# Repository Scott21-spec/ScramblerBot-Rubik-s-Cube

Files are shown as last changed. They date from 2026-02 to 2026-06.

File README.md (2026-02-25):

# ScramblerBot-Rubik's-Cube-For WCA Competitions
Robot capaz de resolver o desarmar cualquier cubo de rubik 3x3 con el uso servomotores, cámara e inteligencia artificial para la detección de colores, figuras o números.

Es la mejor opción para su uso en las competencias internacionales y nacionales de cubo de rubik (WCA), debido a que sólo se coloca el cubo dentro del robot sin necesidad de modificar el cubo o utilizar un cubo especial para su reconocimiento del estado actual.

Modos de uso:
  - Modo de Desordenamiento (Scrambler mode): 
En este modo, el sistema actúa como un actuador esclavo para competencias oficiales. Recibe de forma remota una secuencia de desordenamiento (algoritmo de scramble) validada por la WCA. Tras la ejecución mecánica automatizada de los movimientos, el servidor web local genera un reporte digital en formato PDF. Este documento incluye el registro exacto de la secuencia aplicada, el algoritmo de resolución correspondiente y representaciones gráficas del estado final del cubo (planos 2D y renderizado 3D). Por normativas de seguridad y confidencialidad competitiva, el acceso a este reporte es de carácter restringido, alojándose únicamente en el entorno del servidor para la validación exclusiva de los jueces o administradores del torneo.

  - Modo de Autogeneración y Entrenamiento (Auto-Scramble & Practice Mode):
Concebida como una herramienta de entrenamiento para competidores (speedcubers), esta modalidad permite al microcontrolador generar de manera autónoma una secuencia aleatoria de desordenamiento que cumple estrictamente con los estándares y métricas de la WCA. Una vez que el robot aplica mecánicamente la secuencia generada, el sistema emite un reporte digital homólogo al de la Modalidad 1. A diferencia del modo oficial, este documento es de acceso público y descargable a través de la interfaz web, permitiendo al usuario analizar el estado del cubo, la secuencia aplicada y la solución teórica propuesta para fines de estudio y práctica.

  - Resolución Optimizada (Solve Mode):
Orientada al análisis algorítmico, esta función permite evaluar el estado físico actual de un cubo ingresado por el usuario utilizando el sistema de visión artificial integrado. A partir del mapeo de las caras, el procesador calcula la ruta de resolución más corta (optimizando la cantidad de movimientos requeridos) y procede a su ejecución mecánica. Finalmente, el sistema documenta el proceso generando un reporte descargable que detalla el estado inicial detectado, la cinemática de los movimientos aplicados y la solución óptima ejecutada.

Proyecto de la materia 'Proyecto 3' del 8vo semestre de la carrera Mecatrónica - Facultad de Ingeniería - Universidad Nacional de Asunción - San Lorenzo - Paraguay.

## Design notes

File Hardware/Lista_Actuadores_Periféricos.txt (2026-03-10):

- Servomotores MG996R: (2)
  + Voltaje de operación: 6V
  + Corriente: 500mA - 900mA
  + Corriente maxima: 2.5A
  + Pines: 6V - PWM - GND

- Pantalla LCD 20x4: (1)
  + Voltaje de operación: 5V
  + Corriente: 60mA
  + Pines: 
    *VSS: GND 
    *VDD: 5V
    *Vo: potenciometro (5V y GND en los extremos)
    *RS: PCF8574
    *RW: PCF8574
    *E: PCF8574
    *D4 - D7: PCF8574
    *A: resistencia 220ohm y 5V 
    *K: colector del transistor S8050 (base a PCF8574 con resistencia 4,7kohm a 5V, y emisor a GND)

- Modulo Arducam OV2640: (1)
  + Voltaje de operación: 3.3V
  + Corriente: 200mA
  + Pines: SCK, MOSI, MISO, CS, VCC, GND, SDA, SCL

- MCU ESP32-S3-WROOM-1-N8R8: (1)
  + Clock: 40MHz
  + Voltaje: 3.3V
  + Corriente: 500mA
  + Flash: 8MB Quad SPI
  + SPRAM: 8MB Octal SPI
  + Pines:
    * EN: High -> ON (resistencia de 10k conectado a 3.3V, pulsador conectado a tierra, capacitor 0.1uF a tierra)
    * IO35, I036, IO37: NO USAR (destinado para el PSRAM)
    * IO46, IO47: NO USAR 
    * IO0: conectar a un pulsador a GND

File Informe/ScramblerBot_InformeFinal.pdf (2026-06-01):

SCRAMBLER BOT: ROBOT PARA
LA RESOLUCIÓN DEL CUBO RUBIK

Proyecto MCT
2026

### 1. Resumen del proyecto

El proyecto consiste en el diseño y desarrollo de una placa electrónica para un robot capaz inspeccionar y operar un Cubo de Rubik 3x3 de manera automatizada. El sistema utiliza una cámara para capturar el estado del cubo y un microcontrolador ESP32-S3-WROOM-1 para procesar la información y controlar servomotores encargados de realizar los movimientos necesarios. Además, se incorpora una pantalla LCD manejada por expansores I2C para la visualización del estado del sistema con el tiempo aproximado de demora, y conectividad WiFi para la comunicación con una computadora externa.

### 2. Abstract

The project consists of designing and developing an electronic board for a robot capable of automatically inspecting, and operating a 3x3 Rubik’s Cube. The system uses a camera to capture cube’s state and an ESP32-S3-WROOM-1 microcontroller to process the information and control servomotors responsible for performing the required movements. Additionally, an LCD screen controlled by I2C expanders is included to display system’s status with an approximate delay time, and WiFi connectivity is provided for communication with an external computer.

### 3. Estado del arte

Diversos trabajos han abordado la resolución automática del cubo Rubik mediante la integración de visión artificial, algoritmos de resolución y sistemas robóticos.

[1] David Gilday (ingeniero de ARM Holdings) es el creador de MindCub3r que es un robot de dos actuadores ("brazo/jaula ²

"plataforma giratoria") utilizando LEGOs para demostrar la eficiencia de los procesadores embebidos ARM en ferias tecnológicas internacionales, y en este blog demuestra como logró manipular cubos complejos sin usar decenas de motores.

D. Gilday, "How I Created the ARM Powered Android LEGO Cube Solving Robot,"ARM Developer Community Blogs, Sep. 11, 2013. [Online] Disponible en:

https://developer.arm.com/community/arm-community-blogs/b/internet-of-things-blog/posts/how-i-created-the-arm-powered-android-lego-7x7x7-cube-solving-robot. (https://developer.arm.com/community/arm-community-blogs/b/internet-of-things-blog/posts/how-i-created-the-arm-powered-android-lego-7x7x7-cube-solving-robot)

[2] Uno de los algoritmos más utilizados para la resolución del cubo Rubik es el método
de dos fases desarrollado por Herbert Kociemba. Este algoritmo permite obtener soluciones eficientes en un número reducido de movimientos (aproximadamente 20 movimientos), siendo ampliamente utilizado en aplicaciones robóticas debido a su rapidez y confiabilidad.
H. Kociemba, “Two-Phase Algorithm for Solving Rubik’s Cube,” 2010. [Online] Disponible en:

https://kociemba.org/cube.htm

Camila Cáceres Kowalewski, 0982112185, camila.caceres@fiuna.edu.py Esteban Orlando Ruiz Martinez, 0983518648, eruiz@fiuna.edu.py

[3] En el ámbito de la robótica, existen implementaciones que combinan visión artificial y control de actuadores. Por ejemplo, en el trabajo presentado por Owolabi et al., se desarrolla un robot capaz de resolver el cubo Rubik utilizando procesamiento de imágenes para identificar colores y motores para ejecutar los movimientos.
O. Owolabi, A. O. Adewumi, and O. O. Oladipo, “Development of a Rubik’s Cube Solving Robot,” International Journal of Engineering Research & Technology (IJERT), vol. 8, no. 11, 2019.
[4] Asimismo, en proyectos académicos se ha explorado el uso de plataformas embebidas como Raspberry Pi para integrar la captura de imágenes, el procesamiento y el control de actuadores en un solo sistema, destacando la viabilidad de soluciones compactas y de bajo costo.
S. Tharayil and A. K. S, “Design and Implementation of Rubik’s Cube Solving Robot using Raspberry Pi,” International Journal of Advanced Research in Electrical, Electronics and Instrumentation Engineering, vol. 6, no. 6, 2017.

Estos trabajos demuestran que la resolución automática del cubo Rubik es un problema ampliamente estudiado, donde la combinación de algoritmos eficientes, visión artificial, control de actuadores y una buena elección de la mecánica permite desarrollar sistemas funcionales y de bajo costo. El presente proyecto se basa en estos enfoques, incorporando el diseño de una PCB dedicada para integrar todos los módulos en un sistema compacto.

### 4. Descripción

El proyecto "Scrambler Bot" propone el desarrollo de un prototipo comercial mecatrónico orientado a resolver los cuellos de botella logísticos y los errores humanos (mis-scrambles) presentes en el desordenado manual de los Cubos de Rubik durante competiciones oficiales de la WCA (World Cube Association) y en las sesiones de enseñanza en academias de speedcubing. A diferencia de las costosas alternativas industriales de múltiples motores, este sistema implementa una arquitectura cinemática optimizada de una base giratoria y un brazo manipulador controlada por servomotores de alto torque. Esta solución eficiente se gestiona a través de una placa de circuito impreso (PCB) de diseño propio gobernada por un microcontrolador ESP32-S3, el cual no solo ejecuta las rutinas mecánicas con precisión, sino que integra un módulo de cámara (OV2640) para validar ópticamente el estado del cubo mediante algoritmos de visión artificial, garantizando que el desorden final coincida matemáticamente con el estándar oficial exigido.

La motivación principal detrás de esta iniciativa radica en el gran desafío multidisciplinario que representa, exigiendo la integración armónica de diseño electrónico, programación de sistemas embebidos y diseño. De esta forma, el proyecto busca transformar un problema logístico documentado dentro de la comunidad de speedcubers en un producto de hardware funcional, elegante y asequible, demostrando cómo una ingeniería eficiente puede generar soluciones con un claro potencial de escalabilidad comercial.

### 5. Objetivos

a. General

Diseñar la placa de circuito impreso para el control de un sistema automatizado de resolución del Cubo de Rubik.

b. Específicos
1. Evaluar las alternativas mecánicas para la manipulación del cubo.
2. Diseñar la arquitectura electrónica general del sistema para la alternativa elegida.
3. Seleccionar los componentes adecuados para la implementación de la placa PCB.
4. Realizar el diagrama de bloques del sistema con sus protocolos de comunicación y alimentación correspondientes.
5. Elaborar el esquemático y conexiones de los componentes electrónicos de la placa.
6. Diseñar la PCB integrando el microcontrolador, la cámara, la pantalla LCD, la alimentación y las salidas para actuadores.
7. Implementar las rutinas de software para el control PWM de los actuadores y el procesamiento de la interfaz de visión, validando la comunicación inalámbrica mediante WiFi entre el sistema electrónico y una computadora externa.

### 6. Esquema general del proyecto

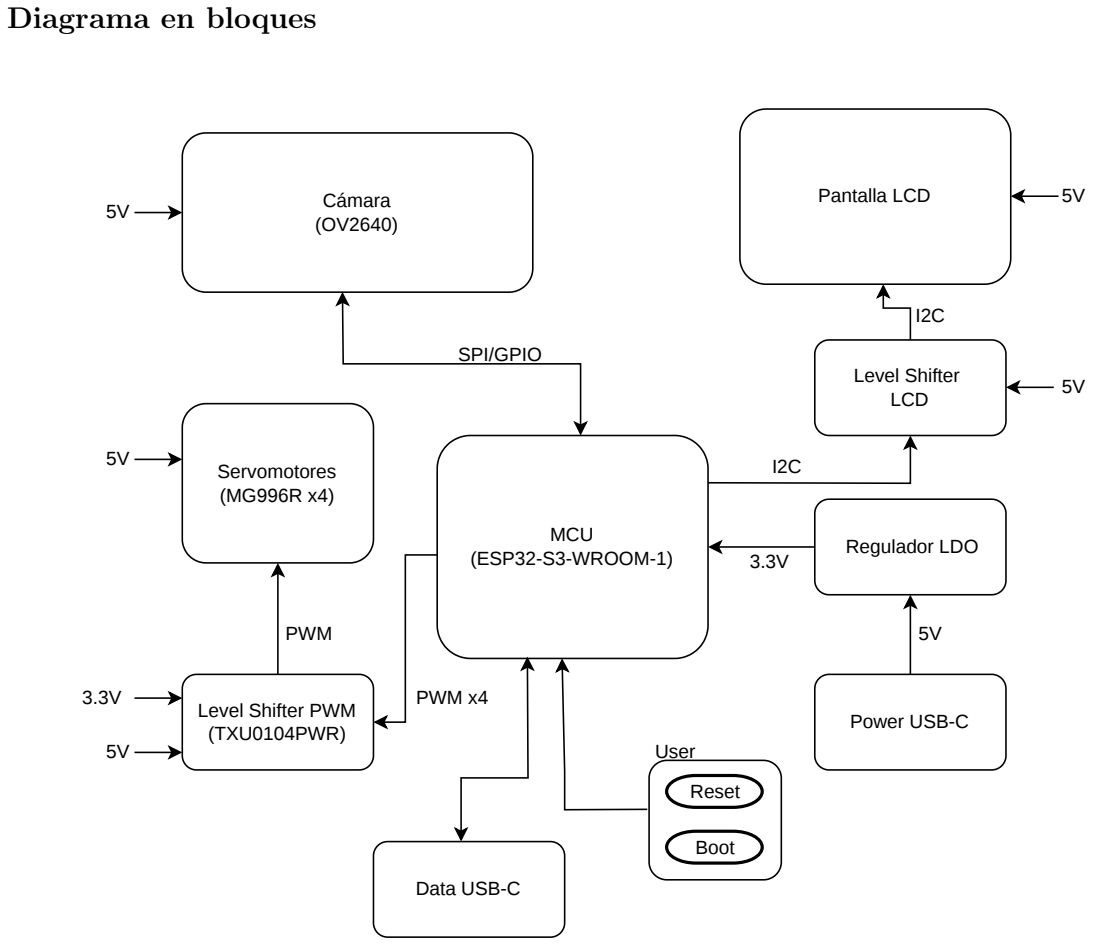
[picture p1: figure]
Diagrama en bloques; MCU (ESP32-S3-WROOM-1); Cámara (OV2640); Level Shifter LCD; Power USB-C; Pantalla LCD; Level Shifter PWM (TXU0104PWR); Servomotores (MG996R x4); Reset; Boot; User; SPI/GPIO; PWM x4; PWM; Regulador LDO; Data USB-C

Descripción de las partes

1. Microcontrolador: ESP32-S3-WROOM-1-N8R8

Encargado de coordinar el funcionamiento general del sistema, procesar la información recibida de los periféricos y generar las señales de control para los actuadores.

Características relevantes:

SoC ESP32-S3 con conectividad WiFi integrada.

Alimentación de 3.3 V.

Múltiples GPIO disponibles.

Soporte para interfaces SPI, PWM, I2C, UART y USB.

Capacidad suficiente para el manejo de periféricos y control del sistema.

2. Módulo cámara OV2640

Se utiliza para la captura de imágenes del cubo Rubik. Su información permite identificar la disposición de colores en las caras del cubo y generar la secuencia de resolución.

Características relevantes:

Alimentación de 5V.

Protocolo SPI.

3. Pantalla LCD

Proporciona una interfaz visual para el usuario, permitiendo mostrar estados del sistema, y viene acompañado de un backpack PCF8574 para que pueda ser controlado mediante el protocolo I2C.

Características relevantes:

Alimentación de 5V.

Preset para ajustar el contraste.

Protocolo I2C.

4. Level Shifter para LCD

Permite adaptar los niveles lógicos entre el ESP32, que opera a 3.3 V, y la pantalla LCD, que opera a 5 V, garantizando compatibilidad en la comunicación I2C.

5. Level Shifter PWM

Convierte las señales PWM del microcontrolador a niveles apropiados para el control de servomotores alimentados a 5 V.

6. Servomotores MG996R

Son los actuadores encargados de manipular físicamente el cubo Rubik. La placa fue diseñada para soportar hasta cuatro salidas PWM, aunque en la implementación actual se utilizan dos servomotores.

Características relevantes:

Alimentación de 5V.

Corriente de bloqueo de 2,5A.

7. Módulo USB-C (Alimentación)

Proporciona la entrada principal de energía del sistema. Incluye protección, filtrado y regulación de voltaje para alimentar tanto la lógica a 3.3 V como los periféricos que operan a 5 V.

8. Módulo USB-C (Datos)

Interfaz de comunicación bidireccional encargada de la carga del firmware en el microcontrolador ESP32-S3 y la depuración del código mediante comunicación serie en tiempo real.

### 6.1. Product Breakdown Structure

## 1. Scrambler Bot

### 1.1. Hardware

### 1.1.1. PCB

1.1.1.1. MCU
1.1.1.2. Level Shifter
1.1.1.2.1. PWM
1.1.1.2.2. LCD
1.1.1.3. I2C Backpack
1.1.1.4. Fuente de Alimentación
1.1.1.4.1. Alimentación
1.1.1.4.1.1. Power USB-C
1.1.1.4.2. Datos
1.1.1.4.2.1. Data USB-C
1.1.1.4.2.2. Protección EDS
1.1.1.4.3. Protección de Retroalimentación de Corriente
1.1.1.5. Regulador LDO

### 1.1.2. Periféricos Externos

1.1.2.1. Módulo Cámara OV2640
1.1.2.2. Pantalla LCD
1.1.2.3. Servomotor MG996R

### 1.2. Software

### 1.2.1. Algoritmo de resolución

1.2.2. Código para controlar periféricos externos.

### 1.2.3. Interfaz de usuario

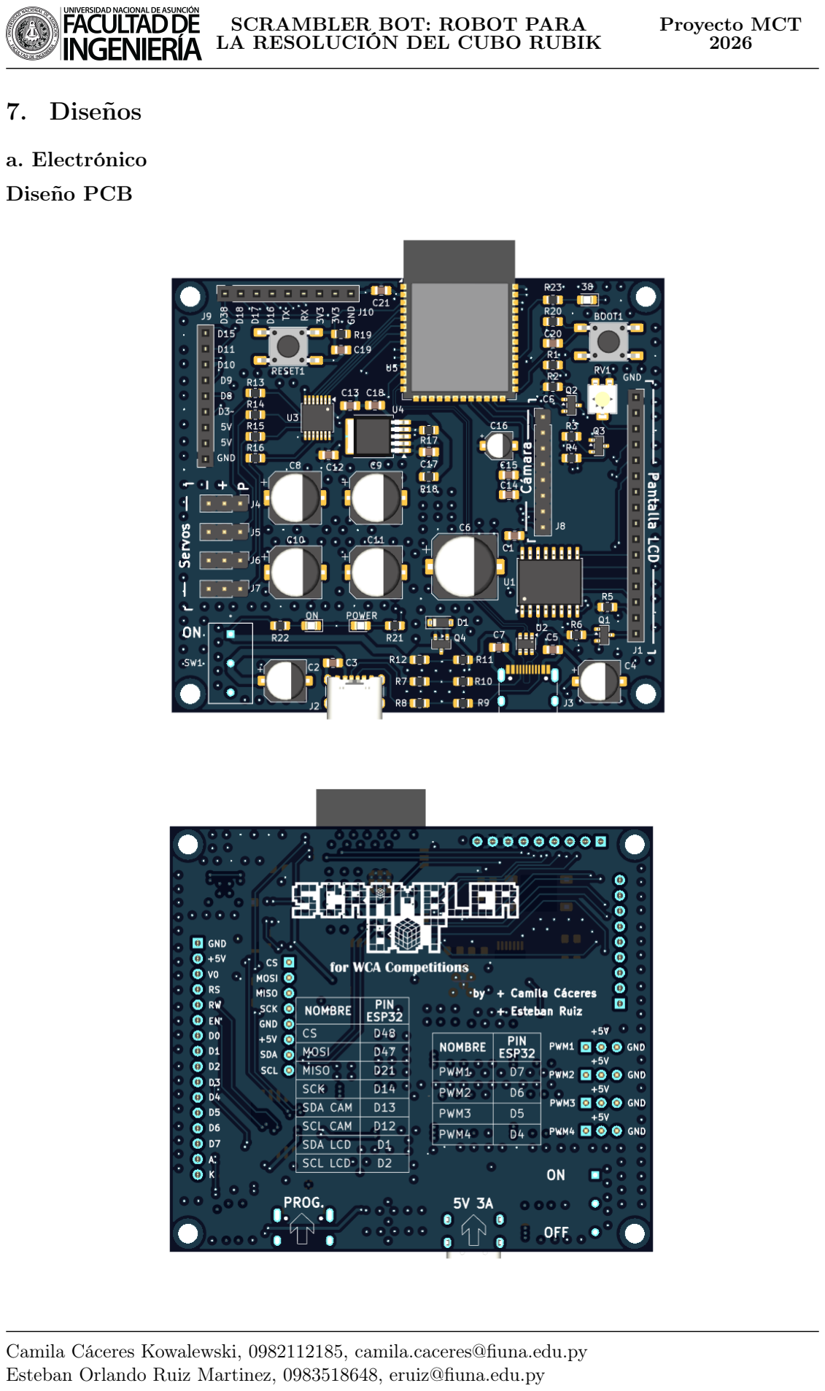
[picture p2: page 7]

### 7. Diseños

a. Electrónico

Diseño PCB

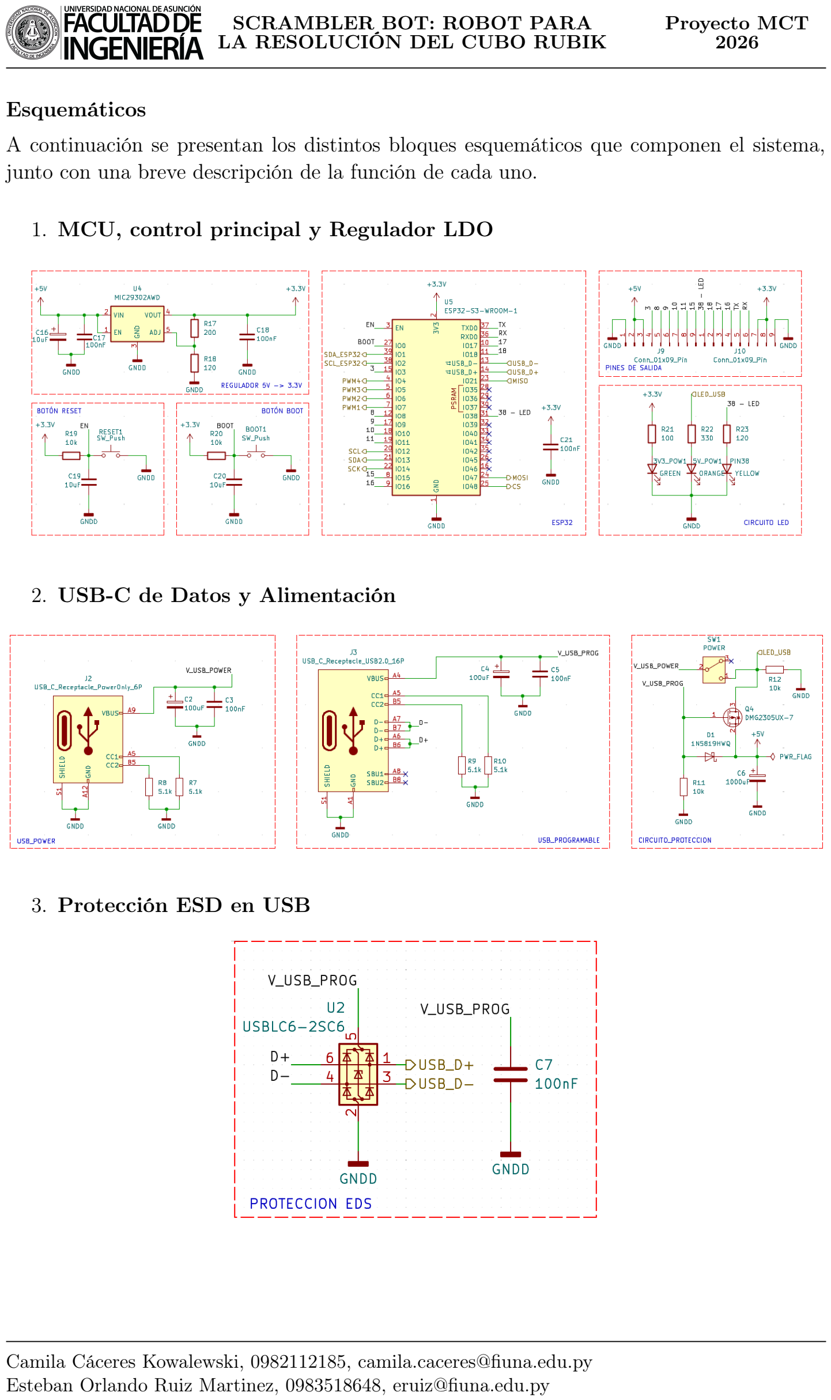
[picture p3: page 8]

Esquemáticos

A continuación se presentan los distintos bloques esquemáticos que componen el sistema, junto con una breve descripción de la función de cada uno.

1. MCU, control principal y Regulador LDO
2. USB-C de Datos y Alimentación
3. Protección ESD en USB

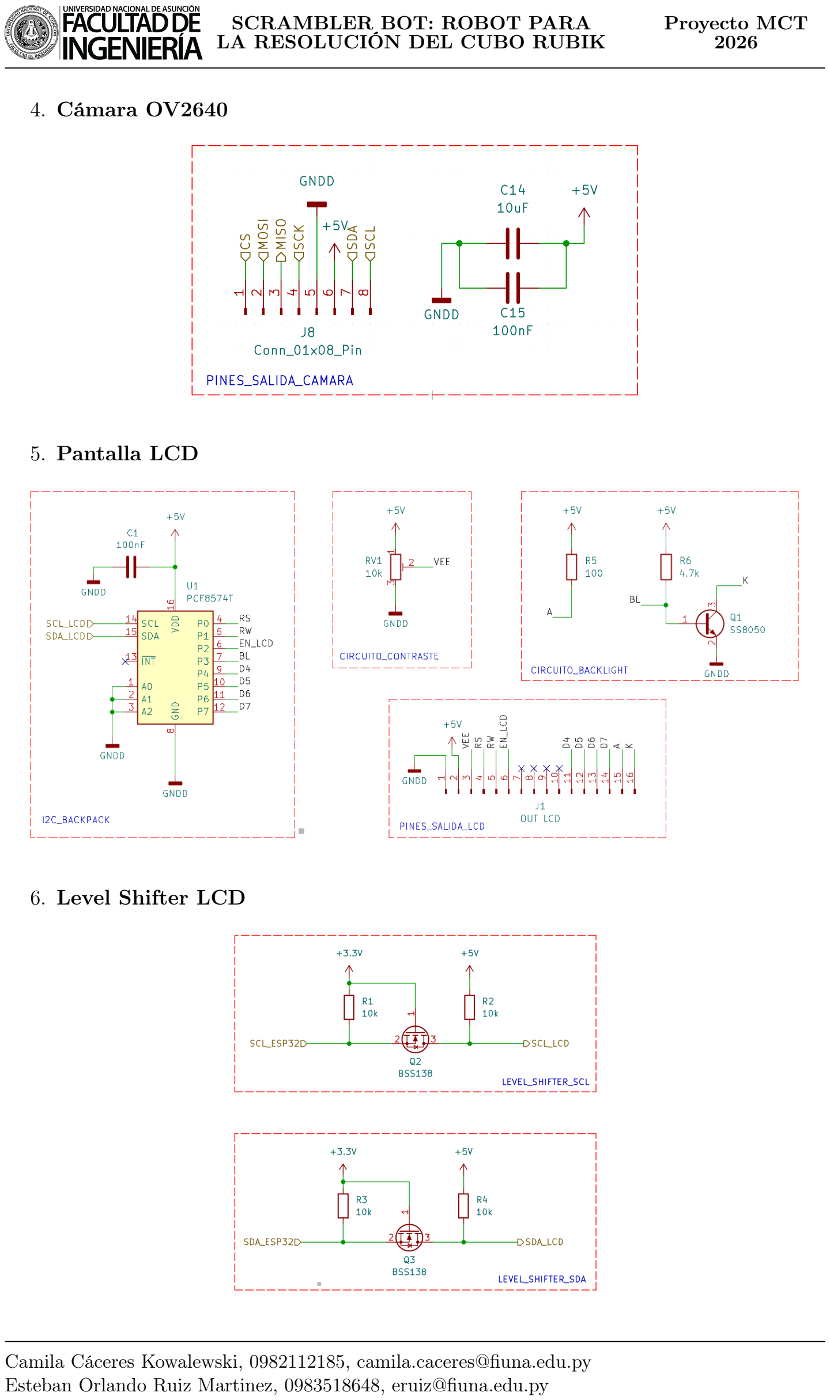
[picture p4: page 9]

4. Cámara OV2640
5. Pantalla LCD
6. Level Shifter LCD

7. Level Shifter PWM

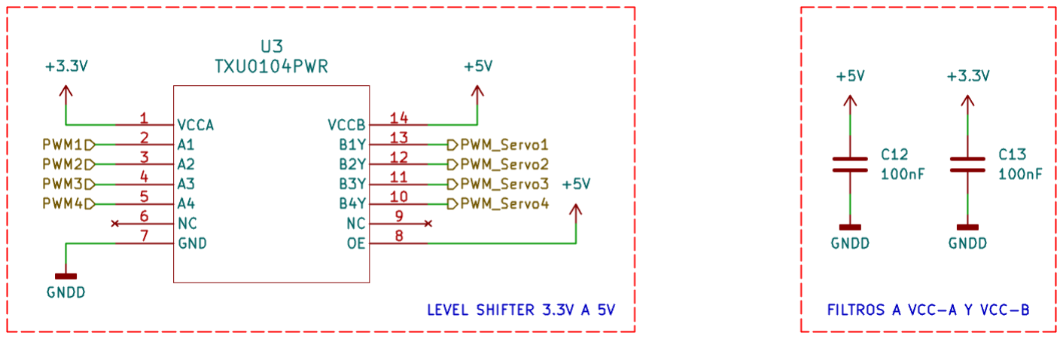
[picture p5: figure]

8. Salidas para servomotores

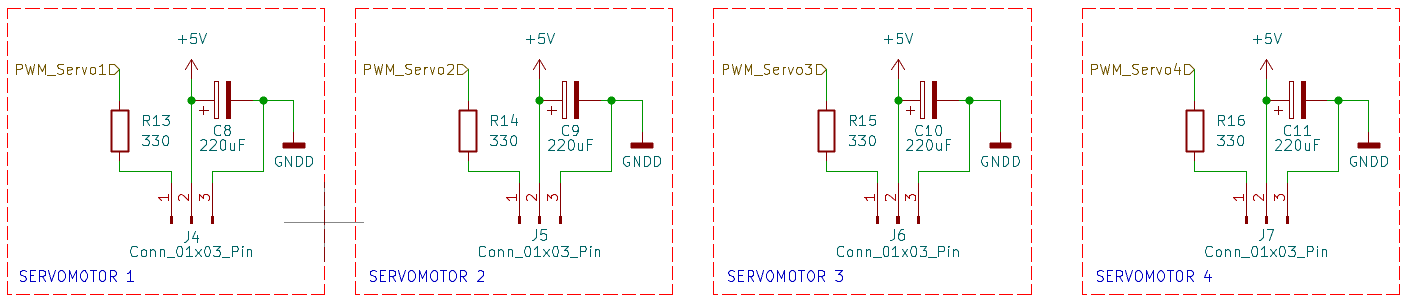
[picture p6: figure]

Descripción:

1. USB-C Datos y Alimentación

Conector USB-C: Entrada principal de energía del sistema (5V, 3A).

Líneas D+ y D-: Utilizadas para programación y comunicación del ESP32.

Capacitores de filtrado: Estabilizan la línea de alimentación de 5V.

2. Protección de alimentación

Diodo Schottky: Evita la retroalimentación de corriente.

MOSFET de protección: Protege frente a sobrecorrientes.

Elementos de filtrado: Reducen ruido eléctrico en la alimentación.

3. Protección ESD en USB

Protección para líneas D+ y D- mediante diodos ESD.

Reduce el riesgo de daño por descargas electrostáticas.

4. Regulador LDO

MIC29302AWD-TR: Regulador encargado de convertir 5V a 3.3V.

Capacitores de entrada y salida: Mejoran la estabilidad y reducen ruido.

Red resistiva: Ajuste de tensión de salida del regulador.

5. Microcontrolador ESP32-S3

ESP32-S3-WROOM-1: Unidad central de procesamiento del sistema.

Interfaces de comunicación: SPI, PWM, I2C, UART y GPIO.

Capacitores de desacoplo: Estabilidad en la alimentación del microcontrolador.

6. Botones de control

Botón RESET: Reinicio del microcontrolador.

Botón BOOT: Permite ingresar en modo de programación.

7. Sistema de cámara

Módulo OV2640: Captura imágenes del cubo Rubik.

Interfaz SPI/GPIO: Comunicación con el ESP32.

Pines dedicados: CS, MISO, MOSI, SCK, SDA y SCL.

8. Pantalla LCD

Interfaz I2C mediante backpack.

Utilizada para visualización del estado del sistema.

Conexión a través de level shifter.

9. Level Shifter LCD

Conversión de niveles lógicos de 3.3V a 5V.

Permite comunicación segura entre ESP32 y LCD.

Implementado con transistores MOSFET.

10. Level Shifter PWM

TXU0104PWR: Conversor de nivel lógico para señales PWM.

Convierte señales de 3.3V a 5V para control de servos.

Soporta hasta 4 canales PWM.

11. Servomotores

Salidas PWM para hasta 4 servomotores.

El sistema utiliza actualmente 2 servos (MG996R).

La PCB está preparada para expansión futura.

12. Pines de conexión

Pines rotulados con +5V, +3.3V, GND y señales de control.

### 8. Costos

a. Materiales y herramientas compradas
Descripción | Cantidad | Precio (USD) | Total (USD)
ESP32-S3-WROOM-1-N8R8 | 1 | 6.23 | 6.23
Regulador LDO de 5V a 3.3V MIC35302WD- TR | 1 | 1.96 | 1.96
LED Naranja (USBPOW ER)HSML−C170− T0000 | 1 | 0.91 | 0.91
LED Verde (GENERALPOW ER)HSMG − C170 | 1 | 0.28 | 0.28
LED Amarillo (Pin 38) HSMY-C170 | 1 | 0.3 | 0.3
Puente de diodos USBLC6-2SC6 | 1 | 0.36 | 0.36
Switch BOOT y RESET 430481025816 | 2 | 0.57 | 1.14
Resistencia 330 CRCW0805330RFKEA | 5 | 0.1 | 0.5
Resistencia 100 CRCW0805100RKNEAIF | 2 | 0.61 | 1.22
Resistencia 200 CRCW0805200RKNEAIF | 1 | 0.61 | 0.61
Resistencia 120 CRCW0805120RFKEA | 2 | 0.1 | 0.2
Resistencia 10k CHP0805AFX-1002ELF | 8 | 0.38 | 3.04
Capacitor 100nF GCM21BR72A104KA37K | 10 | 0.18 | 1.8
Capacitor 10uF GCM21BC71C106KE36K | 3 | 0.41 | 1.23
Capacitor 10uF EEE-FK1C100AR | 1 | 0.45 | 0.45
Regla de 9 pines hembra M20-7820946 | 2 | 1.3 | 2.6
USB-C Alimentacion USB4125-GF-A | 1 | 0.7 | 0.7
Capacitor 100uF EEE-FP1C101AP | 2 | 0.63 | 1.26
Resistencia 5.1k CRCW08055K10FKEA | 4 | 0.1 | 0.4
Capacitor 1000uF EEE-FN1C102UP | 1 | 1.12 | 1.12
Switch 7101SYZQE | 1 | 7.52 | 7.52
USB-C Datos USB4105-GF-A | 1 | 0.94 | 0.94
Diodo Schottky 1N5819HWQ-7-F | 1 | 0.43 | 0.43
MOSFET DMG2305UXQ-7 | 1 | 0.36 | 0.36
Regla de 16 pines hembra 61301611821 | 1 | 0.69 | 0.69
Regla de 40 pines macho 61304011121 | 1 | 1.53 | 1.53
MOSFET BSS138LT3G | 2 | 0.28 | 0.56
PCF8574DWR | 1 | 1.99 | 1.99
Capacitor 220uF EEE-FK1C221P | 4 | 0.7 | 2.8
Level Shifter de 4 canales TXU0104PWR | 1 | 0.99 | 0.99
Trimmer 10k 3314G-1-103E | 1 | 1.58 | 1.58
Transistor SS8050-HF | 1 | 0.29 | 0.29
Resistencia 4,7k CRCW08054K70FKEA | 1 | 0.10 | 0.10
Modulo Arducam OV2640 | 1 | 25.99 | 25.99
| | Costo total | 72.08 USD

b. Materiales y herramientas existentes
Componente | Cantidad
Servomotor MG996R Pantalla LCD 20x4 Flux en pasta Estaño en pasta SN67PB37 Malla de cobre | 4 1 1 1 1

### 9. Montaje, horneado y pruebas

### 9.1. Procedimiento de montaje y horneado de la PCB

El montaje de la placa se realizó en la facultad utilizando el método de soldadura por pasta de estaño y horno de refusión. La PCB y los componentes fueron adquiridos por separado, incluyendo también el stencil correspondiente al diseño de la placa.

Debido a que el fabricante JLCPCB envía un mínimo de cinco placas iguales por pedido, se utilizaron algunas de las placas sobrantes para facilitar el proceso de ensamblado. Tres placas fueron fijadas sobre la mesa de trabajo con cinta adhesiva, formando una base de apoyo que permitió inmovilizar la PCB principal y mantenerla alineada durante la aplicación de la pasta de estaño.

El procedimiento seguido fue el siguiente:

1. Se colocó la PCB principal en el centro de la base de apoyo y se alineó cuidadosamente el stencil con las huellas de los componentes SMD.
2. Una vez alineado el stencil, se aplicó estaño en pasta sobre la superficie.
3. Con ayuda de una tarjeta, se distribuyó la pasta de estaño sobre el stencil. Primero se realizó el arrastre con un ángulo aproximado de 45 grados, luego con un ángulo cercano a 30 grados para mejorar la distribución y finalmente se pasó la tarjeta a 90 grados para retirar el exceso de pasta.
4. Luego de aplicar la pasta, se retiró cuidadosamente el stencil para evitar desplazar el estaño depositado sobre las huellas.
5. Posteriormente, se colocaron los componentes SMD sobre la placa utilizando pinzas y verificando su orientación, especialmente en componentes polarizados como diodos, LEDs, capacitores electrolíticos, conectores USB-C y circuitos integrados.
6. Una vez colocados los componentes, la PCB fue llevada al horno de refusión disponible en la facultad.
7. En el horno se seleccionó la curva de temperatura correspondiente al tipo de estaño en pasta utilizado. El proceso incluyó una etapa inicial de precalentamiento y posteriormente una curva de temperatura que alcanzó aproximadamente los 240 ◦C durante un tiempo cercano a 8 minutos, permitiendo la correcta fusión de la pasta de estaño y el soldado de los componentes SMD.
8. Finalizado el horneado, se dejó enfriar la placa y se realizó una inspección visual de las soldaduras, verificando posibles cortocircuitos, componentes desplazados o uniones incompletas.

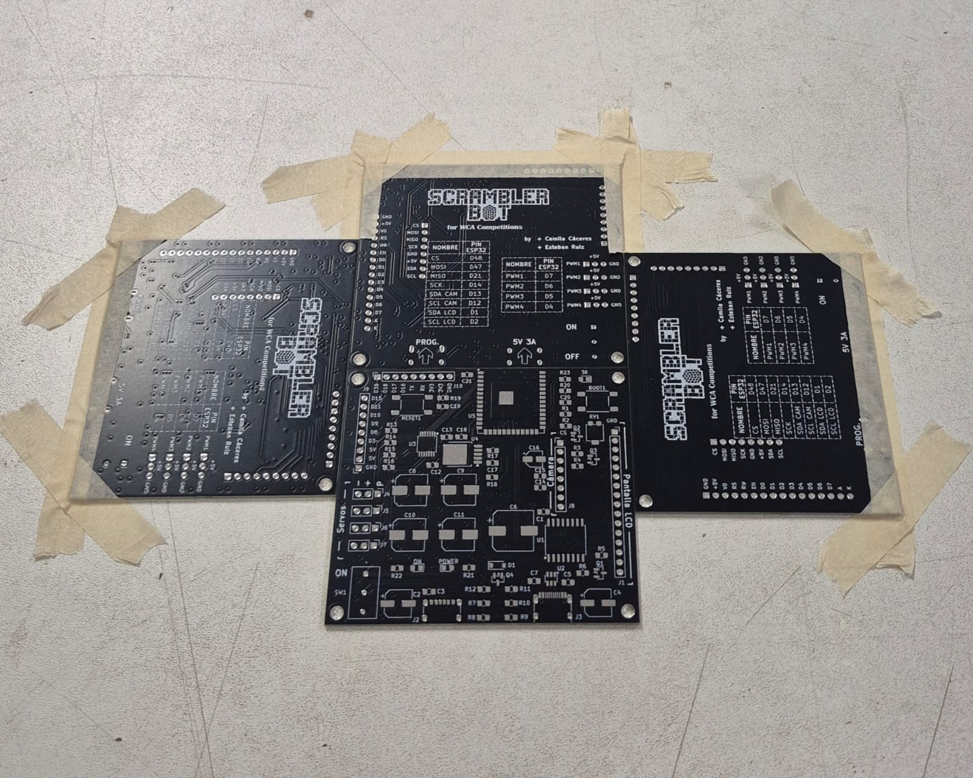
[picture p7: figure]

Figura 1: Inmovilización de la PCB utilizando placas sobrantes del pedido.

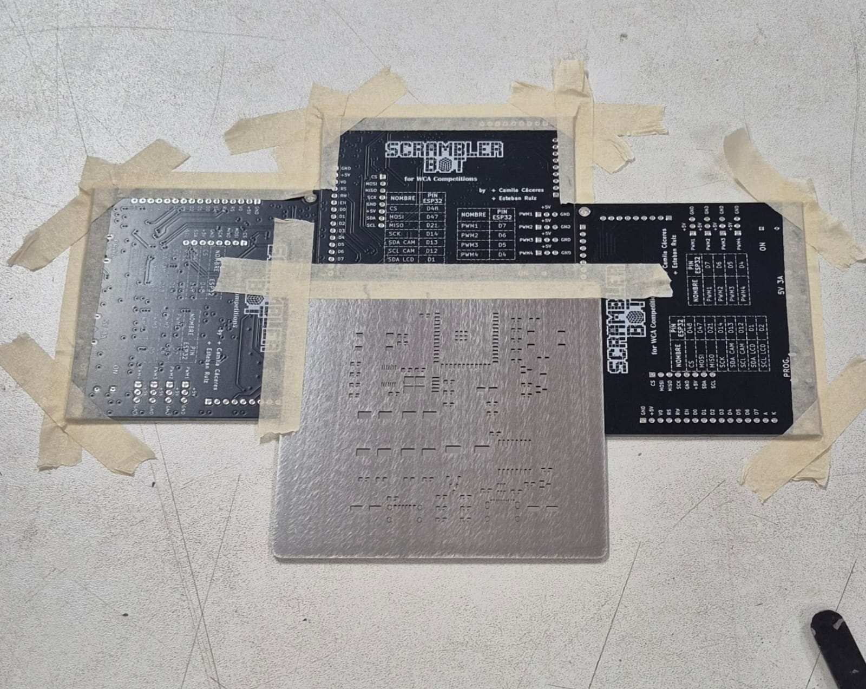
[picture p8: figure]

Figura 2: Aplicación de pasta de estaño utilizando stencil.

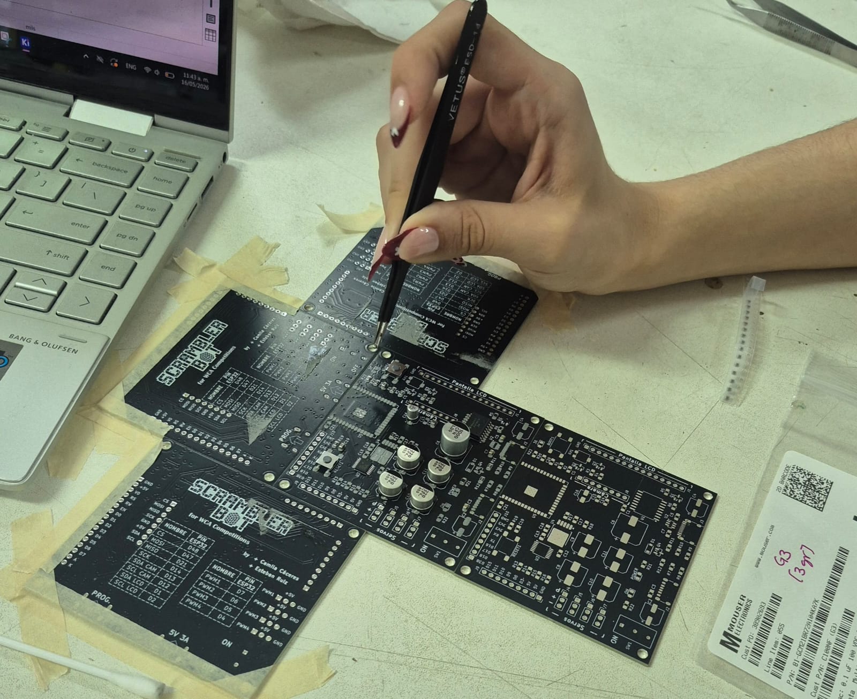
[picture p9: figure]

Figura 3: Colocación manual de componentes SMD utilizando pinzas.

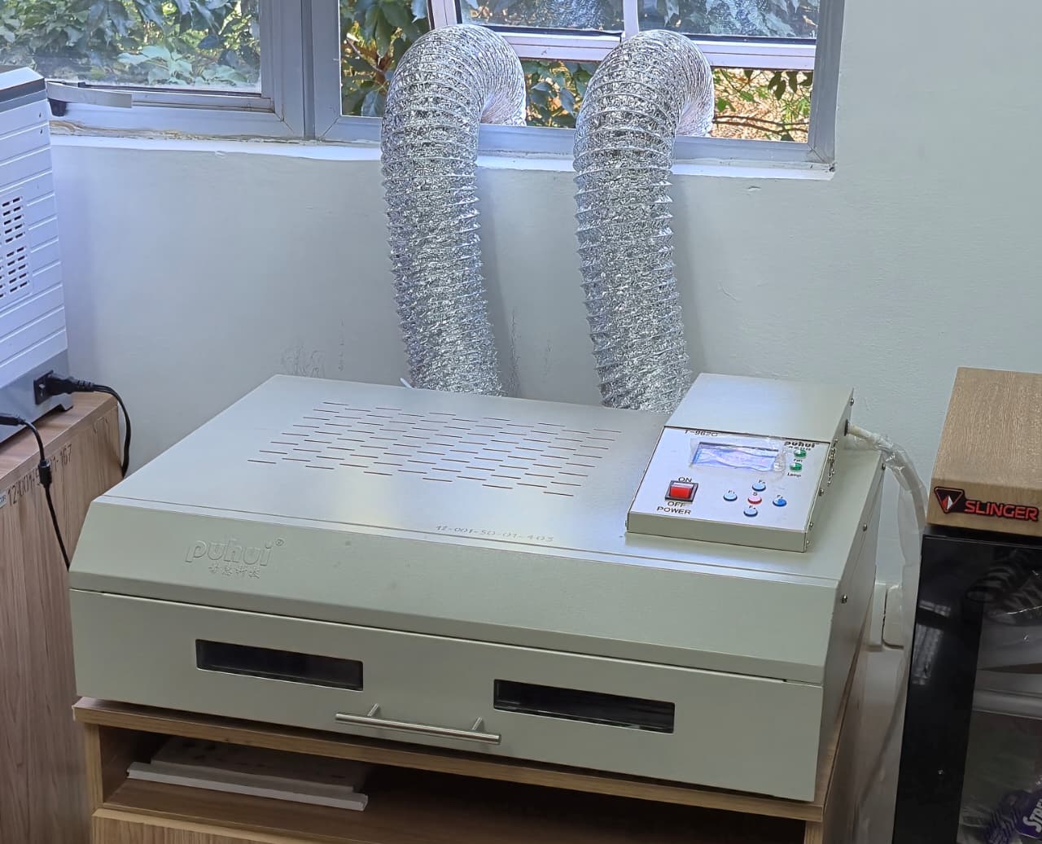
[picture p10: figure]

Figura 4: Proceso de horneado de la PCB en horno de refusión.

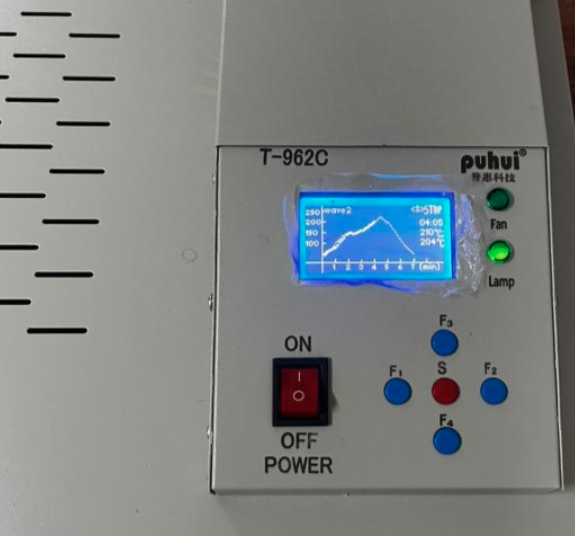
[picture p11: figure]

Figura 5: Curva de temperatura utilizada durante el proceso de soldadura SMD.

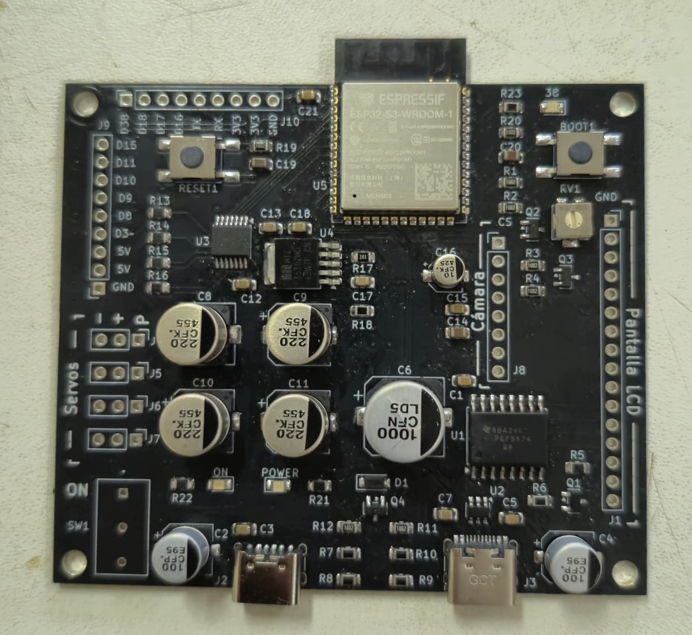
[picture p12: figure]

Figura 6: PCB luego del proceso de montaje y horneado.

### 9.2. Problemas encontrados y soluciones aplicadas

Durante el montaje y las primeras verificaciones de la placa se identificaron algunos problemas que fueron corregidos manualmente.

1. Cortocircuito en conectores USB-C

Se detectaron cortocircuitos entre algunas patas de ambos conectores USB-C. Este problema se debió al exceso de estaño acumulado entre pines durante el proceso de soldadura.

Para solucionarlo, se inspeccionó la zona utilizando un microscopio, se aplicó flux sobre los pines afectados y se pasó cuidadosamente el soldador sobre las patas del conector. Además, se utilizó malla de cobre para retirar el exceso de estaño presente entre algunos terminales.

Luego de realizar esta corrección, visualmente ya no se observaban cortocircuitos; sin embargo, al verificar nuevamente con un multímetro se detectó que el problema persistía en el conector USB de programación.

Con ayuda del profesor, se utilizó cinta térmica y una estación de aire caliente para calentar cuidadosamente el área del conector USB-C y reposicionarlo ligeramente hacia atrás. Esto permitió corregir la alineación del componente sobre la huella de la PCB, eliminando finalmente el cortocircuito detectado.

2. Huella incorrecta en uno de los switches

Se identificó que la huella seleccionada para uno de los switches no coincidía correctamente con el componente físico adquirido. Debido a esto, no fue posible montarlo de manera directa sobre la PCB.

La solución implementada fue realizar una conexión mediante cables, soldando manualmente los terminales necesarios para mantener la funcionalidad del interruptor dentro del circuito.

Luego de estas correcciones, la placa pudo ser energizada y utilizada para realizar pruebas básicas de funcionamiento.

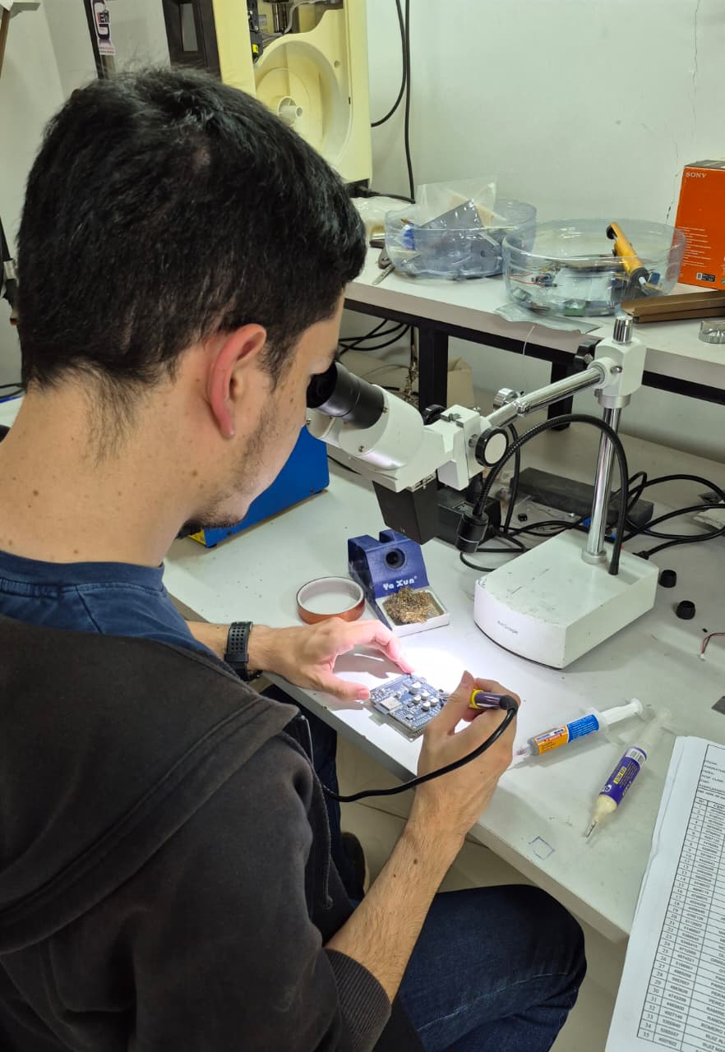
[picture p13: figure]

Figura 7: Inspección y corrección de cortocircuitos en los conectores USB-C utilizando microscopio y soldador.

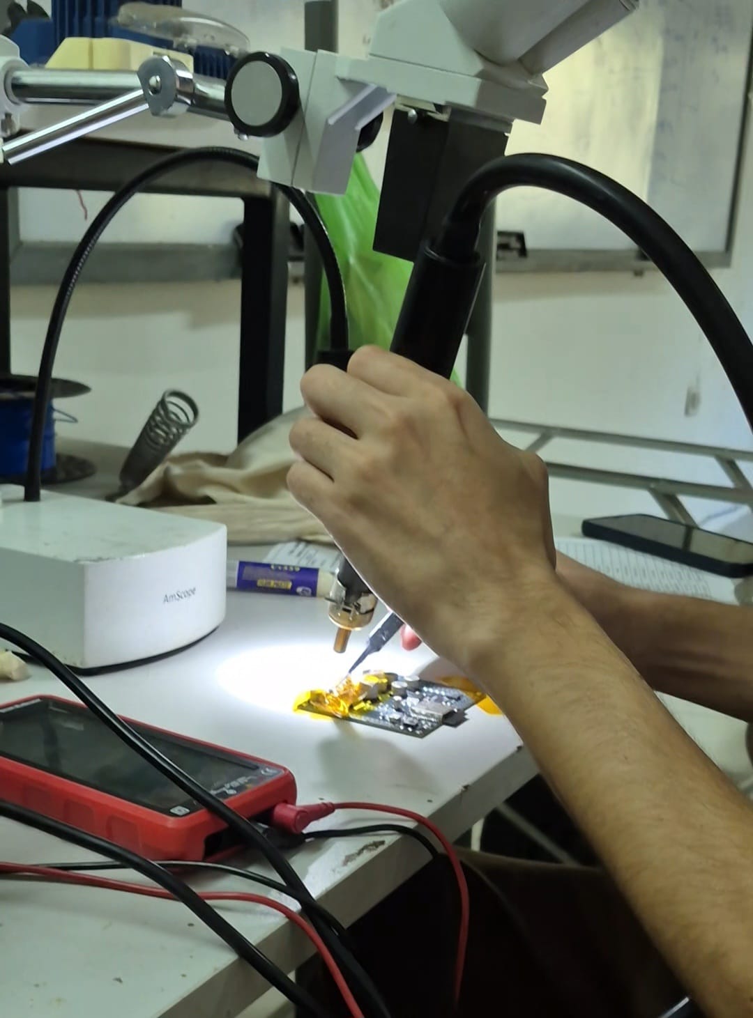
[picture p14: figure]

Figura 8: Corrección de cortocircuitos y reposicionamiento del conector USB-C de programación utilizando estación de aire caliente y cinta térmica.

### 9.3. Avances de programación (ESP-IDF)

### 9.3.1. Prueba 1: Parpadeo del LED de la placa (Blink del Pin 38)

1 | // Incluimos las librerias principales
2 | # include < stdio .h >
3 | # include " freertos / FreeRTOS .h"
4 | # include " freertos / task .h"
5 | # include " driver / gpio .h"

6
7 | # define BLINK_GPIO 38 | // LED de la placa -> GPIO 38

8
9 | static uint8_t estado = 0; | // Estado actual del led

10
11 | void app_main ( void )
12 | {
13 | // Resetear y configurar el GPIO 38 como salida
14 | gpio_reset_pin ( BLINK_GPIO ) ;
15 | gpio_set_direction ( BLINK_GPIO , GPIO_MODE_OUTPUT ) ;

16
17 | while (1) {
18 | gpio_set_level ( BLINK_GPIO , estado ) ;
19 | estado = ! estado ; // Cambia entre 0 y 1
20 | // Delay de 500 ms usando los ticks del RTOS
21 | vTaskDelay (500 / portTICK_PERIOD_MS );
22 | }
23 | }
Listing 1: Código de parpadeo (Blink) en ESP-IDF

Utilizamos las siguientes librerías:

stdio.h: librería estándar de entrada y salida de C.

freertos/FreeRTOS.h: el núcleo del sistema operativo necesario para que el ESP32 pueda gestionar tareas y tiempo.

freertos/task.h: librería específica de FreeRTOS para utilizar vTaskDelay (permite aplicar delays que no bloquean al procesador.

driver/gpio.h: controlador de los pines GPIO; se utiliza para: resetear el estado actual del pin (gpio_reset_pin), configurar como entrada o salida (gpio_set_direction) y para definir el nivel lógico (HIGH o LOW) de la salida (gpio_set_level).

Con la variable estática estado se controla el nivel lógico del pin del led de la placa que es el GPIO 38.

### 9.3.2. Prueba 2: Pantalla LCD mediante comunicación I2C

1 | # include < stdio .h >
2 | # include " freertos / FreeRTOS .h"
3 | # include " freertos / task .h"
4 | # include " driver /i2c.h"
5 | # include " driver / gpio .h"

6
7 | // Definicion de pines I2C para ScramblerBot
8 | # define SDA_PIN 1
9 | # define SCL_PIN 2
10 | # define I2C_PORT I2C_NUM_0
11 | # define LCD_ADDR 0 x20

12
13 | // Funcion para enviar medio byte ( nibble ) manejando el pin ENABLE
14 | void lcd_send_nibble ( uint8_t data , uint8_t rs ) {
15 | uint8_t d = ( data & 0 xF0 ) | 0 x08 | rs ; // 0 x08 enciende el backlight
16 | uint8_t d_en = d | 0 x04 ; // Pulso ENABLE HIGH
17 | // Enviamos datos en I2C con EN = HIGH
18 | i2c_master_write_to_device ( I2C_PORT , LCD_ADDR , & d_en , 1 , 100) ;
19 | vTaskDelay (1 / portTICK_PERIOD_MS ) ;
20 | uint8_t d_dis = d & ~0 x04 ; // Pulso ENABLE LOW
21 | // Enviamos datos en I2C con EN = LOW
22 | i2c_master_write_to_device ( I2C_PORT , LCD_ADDR , & d_dis , 1 , 100) ;
23 | vTaskDelay (1 / portTICK_PERIOD_MS ) ;
24 | }

25
26 | // Enviar byte completo separado en dos nibbles
27 | void lcd_send_byte ( uint8_t data , uint8_t rs ) {
28 | lcd_send_nibble ( data , rs ) ;
29 | lcd_send_nibble ( data << 4 , rs ) ;
30 | }

31
32 | // Comandos (rs = 0) y texto (rs = 1)
33 | void lcd_cmd ( uint8_t cmd ) {
34 | lcd_send_byte ( cmd , 0) ;
35 | }
36 | void lcd_data ( uint8_t data ) {
37 | lcd_send_byte ( data , 1) ;
38 | }

39
40 | // Comando de set cursor del lcd
41 | void lcd_set_cursor ( uint8_t col , uint8_t row ) {
42 | // Direcciones de las filas
43 | uint8_t row_offsets [] = {0 x00 , 0 x40 };
44 | lcd_cmd (0 x80 | ( col + row_offsets [ row ]) ) ; | // 0 x80 -> mover cursor
45 | }

46
47 | // Imprimir texto
48 | void lcd_print ( const char * str ) {
49 | while (* str ) {
50 | lcd_data (( uint8_t ) (* str ++) ) ;
51 | }

52 | }
53 | // Inicializamos la pantalla
54 | // Se envia tres veces la orden de despertar (0 x30 )
55 | // 0 x20 -> modo 4 bits
56 | // 0 x28 -> 4 bits y 2 lineas
57 | void lcd_init () {
58 | vTaskDelay (50 / portTICK_PERIOD_MS ) ;
59 | lcd_send_nibble (0 x30 , 0) ;
60 | vTaskDelay (5 / portTICK_PERIOD_MS ) ;
61 | lcd_send_nibble (0 x30 , 0) ;
62 | vTaskDelay (1 / portTICK_PERIOD_MS ) ;
63 | lcd_send_nibble (0 x30 , 0) ;
64 | vTaskDelay (1 / portTICK_PERIOD_MS ) ;
65 | lcd_send_nibble (0 x20 , 0) ;
66 | vTaskDelay (1 / portTICK_PERIOD_MS ) ;
67 | lcd_cmd (0 x28 ) ;
68 | lcd_cmd (0 x0C ) ; // Display ON
69 | lcd_cmd (0 x01 ) ; // Limpiar pantalla
70 | vTaskDelay (2 / portTICK_PERIOD_MS ) ;
71 | }

72
73 | void app_main ( void )
74 | {
75 | // Configuracion de periferico I2C
76 | i2c_config_t conf = {
77 | . mode = I2C_MODE_MASTER ,
78 | . sda_io_num = SDA_PIN ,
79 | . scl_io_num = SCL_PIN ,
80 | . sda_pullup_en = GPIO_PULLUP_ENABLE ,
81 | . scl_pullup_en = GPIO_PULLUP_ENABLE ,
82 | . master . clk_speed = 100000 ,
83 | };
84 | i2c_param_config ( I2C_PORT , & conf ) ;
85 | i2c_driver_install ( I2C_PORT , conf . mode , 0 , 0 , 0) ;

86
87 | // Inicializacion y escritura
88 | lcd_init () ;
89 | lcd_set_cursor (0 , 0) ;
90 | lcd_print (" Hola soy ") ;
91 | lcd_set_cursor (0 , 1) ;
92 | lcd_print (" ScramblerBot !!") ;
93 | }
Listing 2: Pantalla LCD 16x2 vía I2C en ESP-IDF

Además de las librerías ya utilizadas en la anterior prueba, usaremos la librería del controlador I2C (driver/i2c.h.

La idea principal de este programa es que se encarga de configurar el bus I2C para que el ESP32 controle una pantalla LCD mediante el envío directo de comandos binarios al expansor PCF8574. Inicializa el hardware manualmente en modo de 4 bits, activa la luz de fondo y gestiona la posición del cursor. Finalmente, traduce cadenas de texto en señales eléctricas para mostrar mensajes personalizados en ambas filas del display.

### 9.3.3. Prueba 3: Servomotores

1 | # include < stdio .h >
2 | # include " freertos / FreeRTOS .h"
3 | # include " freertos / task .h"
4 | # include " driver / ledc .h"

5
6 | // Definicion de hardware y PWM
7 | # define SERVO_PIN | 7
8 | # define LEDC_TIMER | LEDC_TIMER_0
9 | # define LEDC_MODE | LEDC_LOW_SPEED_MODE
10 | # define LEDC_CHANNEL | LEDC_CHANNEL_0
11 | # define LEDC_DUTY_RES | LEDC_TIMER_14_BIT
12 | # define LEDC_FREQUENCY | 50

13
14 | // Rangos de calibracion del servo MG996R
15 | # define SERVO_MIN_PULSEWIDTH_US 500
16 | # define SERVO_MAX_PULSEWIDTH_US 2400
17 | # define SERVO_MAX_DEGREE | 180

18
19 | // Conversion de angulos a resolucion de Duty Cycle de 14 bits
20 | uint32_t angle_to_duty ( int angle ) {
21 | uint32_t pulsewidth = SERVO_MIN_PULSEWIDTH_US +
22 | (( SERVO_MAX_PULSEWIDTH_US - SERVO_MIN_PULSEWIDTH_US ) * angle ) /
| SERVO_MAX_DEGREE ;

23
24 | // ( pulsewidth * resolucion_14bits ) / periodo_20ms
25 | return ( pulsewidth * 16384) / 20000;
26 | }

27
28 | void app_main ( void ) {
29 | // Configuracion de temporizador de 50 Hz
30 | ledc_timer_config_t ledc_timer = {
31 | . speed_mode | = LEDC_MODE ,
32 | . timer_num | = LEDC_TIMER ,
33 | . duty_resolution | = LEDC_DUTY_RES ,
34 | . freq_hz | = LEDC_FREQUENCY ,
35 | . clk_cfg | = LEDC_AUTO_CLK
36 | };
37 | ledc_timer_config (& ledc_timer ) ;

38
39 | // Configuracion de canal al pin GPIO 7
40 | ledc_channel_config_t ledc_channel = {
41 | . speed_mode | = LEDC_MODE ,
42 | . channel | = LEDC_CHANNEL ,
43 | . timer_sel | = LEDC_TIMER ,
44 | . intr_type | = LEDC_INTR_DISABLE ,
45 | . gpio_num | = SERVO_PIN ,
46 | . duty | = angle_to_duty (0) ,
47 | . hpoint | = 0
48 | };
49 | ledc_channel_config (& ledc_channel ) ;

50

51 | // Loop :
52 | while (1) {
53 | for (int pos = 0; pos <= SERVO_MAX_DEGREE ; pos ++) {
54 | ledc_set_duty ( LEDC_MODE , LEDC_CHANNEL , angle_to_duty ( pos ) ) ;
55 | ledc_update_duty ( LEDC_MODE , LEDC_CHANNEL ) ;
56 | vTaskDelay (15 / portTICK_PERIOD_MS ) ;
57 | }

58
59 | for (int pos = SERVO_MAX_DEGREE ; pos >= 0; pos - -) {
60 | ledc_set_duty ( LEDC_MODE , LEDC_CHANNEL , angle_to_duty ( pos ) ) ;
61 | ledc_update_duty ( LEDC_MODE , LEDC_CHANNEL ) ;
62 | vTaskDelay (15 / portTICK_PERIOD_MS ) ;
63 | }
64 | }
65 | }
Listing 3: Control de Servomotor MG996R en ESP-IDF

La librería que se utiliza para el control del servomotor es una librería para controlar la salida PWM (driver/ledc.h).

Este programa configura un temporizador a 50Hz con resolución de 14 bits y traduce matemáticamente los ángulos (0° a 180°) en los anchos de pulso exactos (500µs a 2400µs) que exige el motor. Finalmente, ejecuta un bucle infinito que actualiza continuamente el ciclo de trabajo para realizar un barrido suave de ida y vuelta.

### 9.3.4. Simulación del algoritmo final

1. servo.h
1 | # ifndef SERVO_H
2 | # define SERVO_H
3 | # include < stdint .h >
4 | // Macros publicas del Servomotor
5 | # define SERVO_1_PIN | 7
6 | # define SERVO_2_PIN | 8
7 | # define POS_INICIAL | 0
8 | # define POS_MEDIA | 90
9 | # define TIEMPO_MOV_MS | 500 | // Tiempo para que el servo llegue a
| su posicion

10
11 | // Variable que puede usarse en el main . cpp
12 | extern int contador_movimientos ;

13
14 | // Funciones publicas
15 | void servo_init ( void ) ;
16 | void mover_servos_secuencia ( void ) ;

17
18 | # endif

19
Listing 4: servo.h
2. servo.cpp
1 | # include " servo .h"
2 | # include " driver / ledc .h"
3 | # include " freertos / FreeRTOS .h"
4 | # include " freertos / task .h"

5
6 | // Macros internas de configuracion
7 | # define LEDC_TIMER | LEDC_TIMER_0
8 | # define LEDC_MODE | LEDC_LOW_SPEED_MODE
9 | # define LEDC_CANAL_S1 | LEDC_CHANNEL_0
10 | # define LEDC_CANAL_S2 | LEDC_CHANNEL_1
11 | # define LEDC_RESOLUCION LEDC_TIMER_14_BIT
12 | # define LEDC_FRECUENCIA 50
13 | # define PULSO_MIN | 500
14 | # define PULSO_MAX | 2400
15 | # define GRADOS_MAX | 180

16
17 | // Definicion de la variable extern
18 | int contador_movimientos = 0;

19
20 | // Convierte los angulos en Duty Cycles de 14 bits de resolucion
21 | static uint32_t angle_to_duty ( int angle ) {
22 | uint32_t pulsewidth = PULSO_MIN + (( PULSO_MAX - PULSO_MIN ) *
| angle ) / GRADOS_MAX ;
23 | return ( pulsewidth * 16384) / 20000;
24 | }

25 | // Movemos el servo y esperamos
26 | static void mover_servo ( ledc_channel_t canal , int grados ) {
27 | ledc_set_duty ( LEDC_MODE , canal , angle_to_duty ( grados ) ) ;
28 | ledc_update_duty ( LEDC_MODE , canal ) ;
29 | vTaskDelay ( TIEMPO_MOV_MS / portTICK_PERIOD_MS ) ;
30 | }
31 | // Inicializamos el servo
32 | void servo_init ( void ) {
33 | ledc_timer_config_t timer_conf = {
34 | . speed_mode = LEDC_MODE ,
35 | . duty_resolution = LEDC_RESOLUCION ,
36 | . timer_num = LEDC_TIMER ,
37 | . freq_hz = LEDC_FRECUENCIA ,
38 | . clk_cfg = LEDC_AUTO_CLK
39 | };
40 | ledc_timer_config (& timer_conf ) ;

41
42 | ledc_channel_config_t ch1_conf = {
43 | . gpio_num = SERVO_1_PIN ,
44 | . speed_mode = LEDC_MODE ,
45 | . channel = LEDC_CANAL_S1 ,
46 | . intr_type = LEDC_INTR_DISABLE ,
47 | . timer_sel = LEDC_TIMER ,
48 | . duty = angle_to_duty ( POS_INICIAL ) ,
49 | . hpoint = 0
50 | };
51 | ledc_channel_config (& ch1_conf ) ;

52
53 | ledc_channel_config_t ch2_conf = {
54 | . gpio_num = SERVO_2_PIN ,
55 | . speed_mode = LEDC_MODE ,
56 | . channel = LEDC_CANAL_S2 ,
57 | . intr_type = LEDC_INTR_DISABLE ,
58 | . timer_sel = LEDC_TIMER ,
59 | . duty = angle_to_duty ( POS_INICIAL ) ,
60 | . hpoint = 0
61 | };
62 | ledc_channel_config (& ch2_conf ) ;
63 | }
64 | void mover_servos_secuencia ( void ) {
65 | // Se mueve el servo 1 a 90 grados
66 | mover_servo ( LEDC_CANAL_S1 , POS_MEDIA ) ;
67 | // Se mueve el servo 2 a 90 grados
68 | mover_servo ( LEDC_CANAL_S2 , POS_MEDIA ) ;
69 | // Vuelve a posicion original el servo 2
70 | mover_servo ( LEDC_CANAL_S2 , POS_INICIAL );
71 | // Vuelve a posicion original el servo 1
72 | mover_servo ( LEDC_CANAL_S1 , POS_INICIAL );
73 | contador_movimientos ++;
74 | }

75
Listing 5: servo.cpp

### 3. lcd.h

1 | # ifndef LCD_H
2 | # define LCD_H
3 | # include < stdint .h >
4 | // Macros publicas de la pantalla lcd
5 | # define SDA_PIN | 1
6 | # define SCL_PIN | 2
7 | # define I2C_PORT | I2C_NUM_0
8 | # define LCD_ADDR | 0 x20

9
10 | // Funciones publicas a utilizar en el main . cpp
11 | void lcd_init ( void ) ;
12 | void lcd_set_cursor ( uint8_t col , uint8_t row );
13 | void lcd_print ( const char * str ) ;
14 | void lcd_clear ( void ) ;

15
16 | # endif

17
Listing 6: lcd.h
4. lcd.cpp
1 | # include " lcd .h"
2 | # include " driver /i2c.h"
3 | # include " freertos / FreeRTOS .h"
4 | # include " freertos / task .h"

5
6 | // Enviar 4 bits a la pantalla lcd
7 | static void lcd_send_nibble ( uint8_t data , uint8_t rs ) {
8 | uint8_t d = ( data & 0 xF0 ) | 0 x08 | rs ;
9 | uint8_t d_en = d | 0 x04 ;
10 | i2c_master_write_to_device ( I2C_PORT , LCD_ADDR , & d_en , 1 , 100)
| ;
11 | vTaskDelay (1 / portTICK_PERIOD_MS ) ;
12 | uint8_t d_dis = d & ~0 x04 ;
13 | i2c_master_write_to_device ( I2C_PORT , LCD_ADDR , & d_dis , 1,
100) ;
14 | vTaskDelay (1 / portTICK_PERIOD_MS ) ;
15 | }

16
17 | // Enviar byte entero a la pantalla lcd
18 | static void lcd_send_byte ( uint8_t data , uint8_t rs ) {
19 | lcd_send_nibble ( data , rs ) ;
20 | lcd_send_nibble ( data << 4 , rs ) ;
21 | }

22
23 | // Comando (rs =0) y texto (rs =1)
24 | static void lcd_cmd ( uint8_t cmd ) {
25 | lcd_send_byte ( cmd , 0) ;
26 | }
27 | static void lcd_data ( uint8_t data ) {
28 | lcd_send_byte ( data , 1) ;
29 | }

30
31 | void lcd_set_cursor ( uint8_t col , uint8_t row ) {
32 | uint8_t row_offsets [] = {0 x00 , 0 x40 };
33 | lcd_cmd (0 x80 | ( col + row_offsets [ row ]) ) ;
34 | }

35
36 | void lcd_print ( const char * str ) {
37 | while (* str ) {
38 | lcd_data (( uint8_t ) (* str ) ) ;
39 | str ++;
40 | }
41 | }

42
43 | void lcd_clear ( void ) {
44 | lcd_cmd (0 x01 ) ;
45 | vTaskDelay (2 / portTICK_PERIOD_MS ) ;
46 | }

47
48 | // Funcion de inicializacion
49 | void lcd_init () {
50 | i2c_config_t conf = {
51 | . mode = I2C_MODE_MASTER , . sda_io_num = SDA_PIN , .
| scl_io_num = SCL_PIN ,
52 | . sda_pullup_en = GPIO_PULLUP_ENABLE , . scl_pullup_en =
| GPIO_PULLUP_ENABLE ,
53 | . master = {. clk_speed = 100000}
54 | };
55 | i2c_param_config ( I2C_PORT , & conf ) ;
56 | i2c_driver_install ( I2C_PORT , conf . mode , 0 , 0 , 0) ;

57
58 | vTaskDelay (50 / portTICK_PERIOD_MS ) ;
59 | lcd_send_nibble (0 x30 , 0) ;
60 | vTaskDelay (5 / portTICK_PERIOD_MS ) ;
61 | lcd_send_nibble (0 x30 , 0) ;
62 | vTaskDelay (1 / portTICK_PERIOD_MS ) ;
63 | lcd_send_nibble (0 x30 , 0) ;
64 | vTaskDelay (1 / portTICK_PERIOD_MS ) ;
65 | lcd_send_nibble (0 x20 , 0) ;
66 | vTaskDelay (1 / portTICK_PERIOD_MS ) ;

67
68 | lcd_cmd (0 x28 ) ;
69 | lcd_cmd (0 x0C ) ; // Display ON
70 | lcd_clear () ;
71 | }

72
Listing 7: lcd.cpp

5. main.cpp
1 | # include < stdio .h >
2 | # include " freertos / FreeRTOS .h"
3 | # include " freertos / task .h"
4 | # include " lcd .h"
5 | # include " servo .h"
6 | // Macros de tiempos
7 | # define TIEMPO_SALUDO_MS | 5000 | // 5 segundos
8 | # define TIEMPO_RESOLVIENDO_MS 10000 | // 10 segundos

9
10 | // El ’extern "C" ’ para que reconozca la funcion principal
11 | extern "C" void app_main ( void )
12 | {
13 | // Inicializacion del hardware
14 | lcd_init () ;
15 | servo_init () ;
16 | // Mensaje inicial
17 | lcd_clear () ;
18 | lcd_set_cursor (0 , 0) ;
19 | lcd_print (" Hola soy ") ;
20 | lcd_set_cursor (0 , 1) ;
21 | lcd_print (" ScramblerBot !!") ;
22 | vTaskDelay ( TIEMPO_SALUDO_MS / portTICK_PERIOD_MS ) ;
23 | // Tomamos la marca de tiempo actual en milisegundos
24 | TickType_t tiempo_inicio = xTaskGetTickCount () *
| portTICK_PERIOD_MS ;
25 | // Mientras no hayan pasado 10 segundos , repetimos la
| secuencia
26 | while ((( xTaskGetTickCount () * portTICK_PERIOD_MS ) -
tiempo_inicio ) < TIEMPO_RESOLVIENDO_MS ) {
27 | \\ Imprimimos en la pantalla
28 | lcd_clear () ;
29 | lcd_set_cursor (0 , 0) ;
30 | lcd_print (" Resolviendo ... ") ;
31 | lcd_set_cursor (0 , 1) ;
32 | lcd_print (" Movimientos : ");
33 | lcd_set_cursor (13 , 1) ;
34 | lcd_print ( contador_movimientos ) ;

35
36 | mover_servos_secuencia () ;
37 | }
38 | // Pausa
39 | vTaskDelay ( TIEMPO_PAUSA_MS / portTICK_PERIOD_MS ) ;
40 | // Mensaje final
41 | lcd_clear () ;
42 | lcd_set_cursor (0 , 0) ;
43 | lcd_print (" Cubo Resuelto !!") ;
44 | }

45
Listing 8: main.cpp

### 9.4. Flujo conceptual del algoritmo

El flujo conceptual del algoritmo final es presentado mediante el siguiente diagrama de flujo. El sistema inicia cuando el usuario presiona el botón de inicio, momento en el cual la cámara comienza la detección de colores de cada cara del cubo Rubik.

Si una cara no es detectada correctamente, el sistema realiza nuevos intentos y, en caso de alcanzar múltiples errores consecutivos, se muestra un mensaje de error en la pantalla LCD.

Una vez detectadas las seis caras del cubo, el ESP32-S3 procesa la información obtenida y calcula la secuencia de movimientos necesaria para resolver el cubo. Posteriormente, se ejecutan los movimientos de los servomotores de manera secuencial hasta completar el algoritmo.

Finalmente, el sistema muestra en la pantalla LCD un mensaje indicando la finalización del proceso.

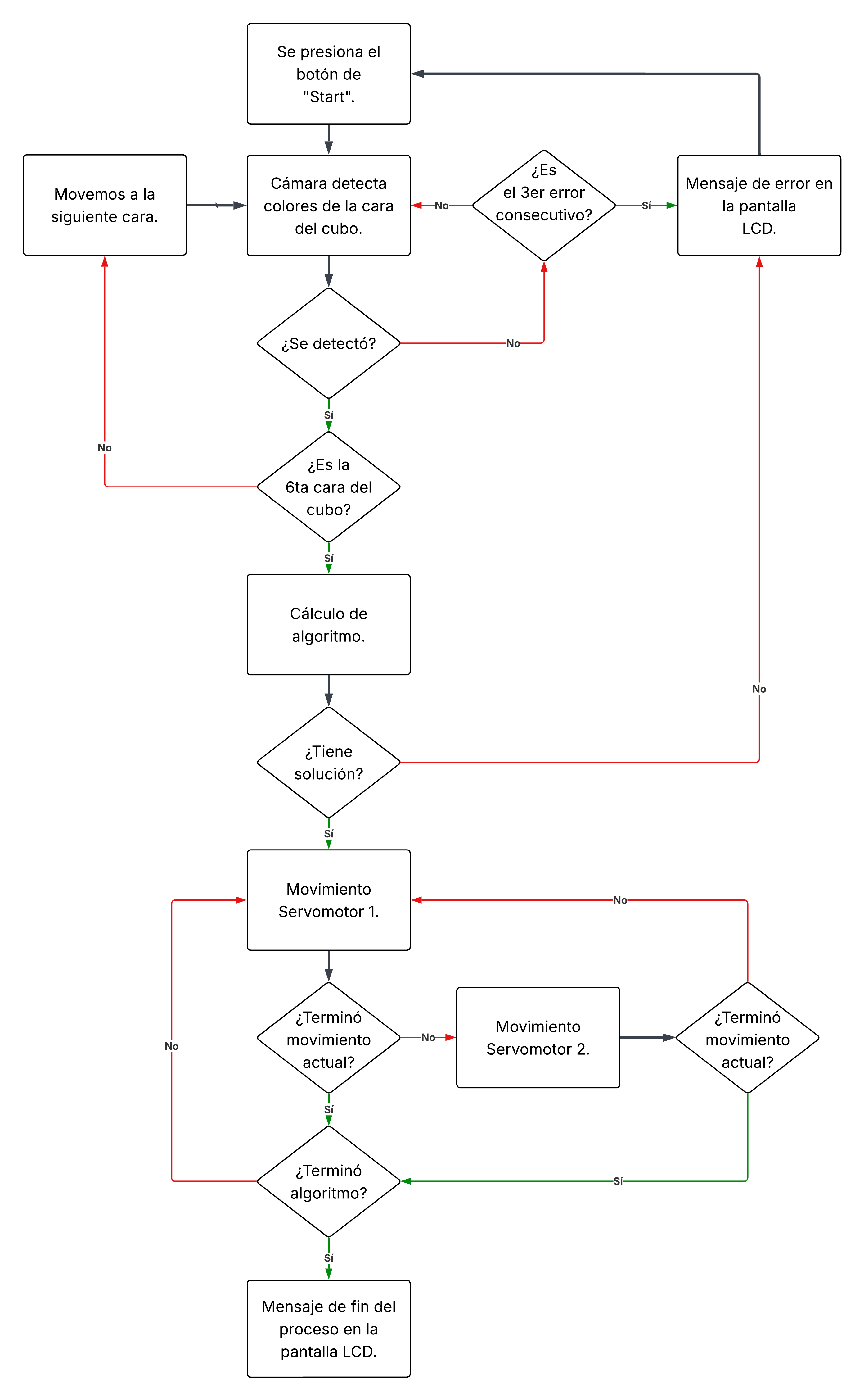
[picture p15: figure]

### 9.5. Resultados de pruebas aisladas

Se realizaron pruebas aisladas para verificar el funcionamiento de algunos módulos principales de la PCB.

1. Prueba de pantalla LCD

Se logró programar la pantalla LCD y mostrar el mensaje:

“Hola soy ScramblerBot!!”

Esta prueba permitió validar la alimentación de la pantalla y la comunicación mediante el bus I2C.

2. Prueba de LED indicador

Se programó correctamente un LED de prueba conectado al pin 38 del ESP32-S3. Esto permitió verificar la configuración de GPIO como salida digital y comprobar que el microcontrolador ejecuta el firmware cargado.

3. Prueba de servomotor

Se conectó un servomotor MG996R a una de las salidas PWM de la placa y se logró generar movimiento mediante programación. Esta prueba permitió validar la etapa de control PWM y la conexión hacia los actuadores.

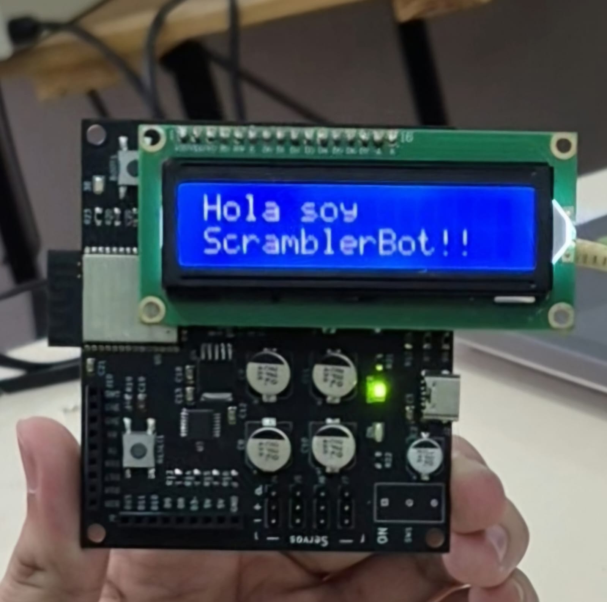
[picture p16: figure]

Figura 9: Prueba de funcionamiento de la pantalla LCD mediante comunicación I2C.

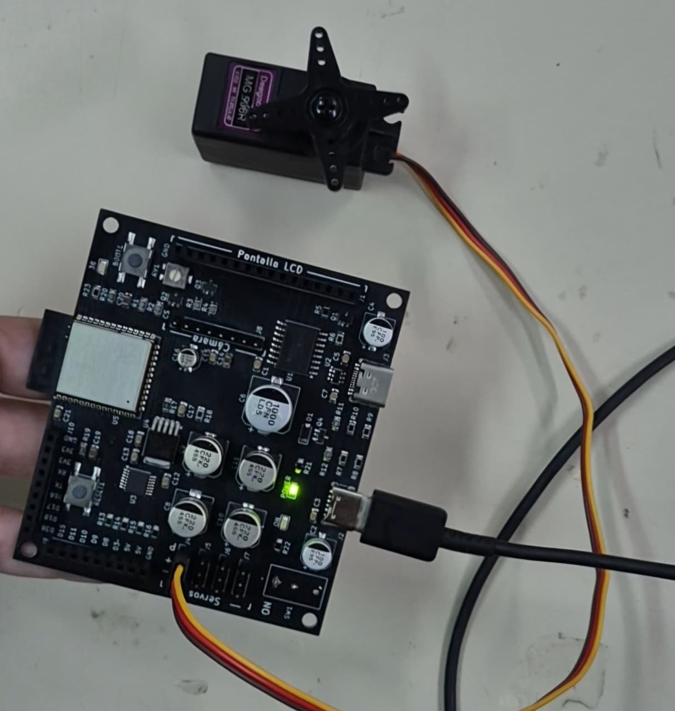
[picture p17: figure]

Figura 10: Prueba de control PWM utilizando un servomotor MG996R.

Los resultados parciales indican que la placa responde correctamente en pruebas básicas de salida digital, comunicación con pantalla LCD y control de actuadores mediante PWM.

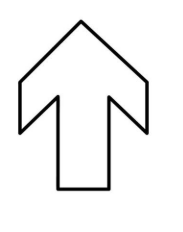
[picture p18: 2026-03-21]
Hardware/Imagenes/flecha.png

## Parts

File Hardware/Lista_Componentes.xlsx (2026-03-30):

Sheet: Componentes por Bloque
Lista de componentes
Bloque | Nombre del componente | Link de compra | Precio Unitario | Cantidad | Precio Total | Datasheet (Opc.)
MCU | ESP32-S3-WROOM-1-N8R8 | https://www.mouser.com/ProductDetail/Espressif-Systems/ESP32-S3-WROOM-1-N8R8 | 6.23 | 2 | 12.46 | https://documentation.espressif.com/esp32-s3-wroom-1_wroom-1u_datasheet_en.pdf |  | https://documentation.espressif.com/esp32-s3_datasheet_en.pdf#cd-pins-peri-assignment
 | LED Naranja (USB_POWER) HSML-C170-T0000 | https://www.mouser.com/ProductDetail/Broadcom-Avago/HSML-C170-T0000 | 0.91 | 2 | 1.82 | 20mA y 1.9V
 | LED Verde (GENERAL_POWER) HSMG-C170 | https://www.mouser.com/ProductDetail/Broadcom-Avago/HSMG-C170 | 0.28 | 2 | 0.56 | 20mA y 2.2V
 | LED Amarillo (Pin 38) HSMY-C170 | https://www.mouser.com/ProductDetail/Broadcom-Avago/HSMY-C170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 | 0.3 | 2 | 0.6 | 20mA y 2.1V
 | Regulador LDO de 5V a 3.3V MIC35302WD-TR | https://www.mouser.mx/ProductDetail/Microchip-Technology/MIC35302WD-TR?qs=U6T8BxXiZAWZXqeFVGyoZQ%3D%3D | 1.96 | 2 | 3.92 | https://www.mouser.mx/datasheet/3/282/1/20005897B.pdf
 | Resistencia 330 CRCW0805330RFKEA | https://www.mouser.com/ProductDetail/Vishay/CRCW0805330RFKEA?qs=TrAHXYCGmqx6h6MysZWe0Q%3D%3D | 0.1 | 2 | 0.2 | 1/4W - 1%
 | Puente de Diodos USBLC6-2SC6 | https://www.mouser.com/ProductDetail/STMicroelectronics/USBLC6-2SC6?qs=po45yt2pPpu%2FhNIlwQdTlg%3D%3D | 0.36 | 2 | 0.72 | https://www.st.com/resource/en/datasheet/usblc6-2.pdf
 | Switch boot y reset 430481025816 | https://www.mouser.es/ProductDetail/Wurth-Elektronik/430481025816?qs=wr8lucFkNMXXxhyqbLxcbg%3D%3D | 0.57 | 4 | 2.28 | https://www.we-online.com/components/products/datasheet/430481025816.pdf
 | Resistencia 10k CHP0805AFX-1002ELF | https://www.mouser.com/ProductDetail/Bourns/CHP0805AFX-1002ELF?qs=BJlw7L4Cy79Jv8LZuArCYQ%3D%3D | 0.38 | 4 | 1.52 | https://www.mouser.com/datasheet/3/40/1/chp_a.pdf |  |  |  | y el resistor también cerca
 | Capacitor 100nF GCM21BR72A104KA37K | https://www.mouser.com/ProductDetail/Murata-Electronics/GCM21BR72A104KA37K?qs=PKjpbm2dS7zQx76EVedSAQ%3D%3D | 0.18 | 2 | 0.36 | 50V |  |  | coloca ese capacitor muy cerca del pin EN del ESP32
 | Capacitor 10uF GCM21BC71C106KE36K | https://www.mouser.com/ProductDetail/Murata-Electronics/GCM21BC71C106KE36K?qs=QzBtWTOodeVTOttr1AxchQ%3D%3D | 0.41 | 6 | 2.46 | 16V
 | Capacitor 10uF EEE-FK1C100AR | https://www.mouser.com/ProductDetail/Panasonic/EEE-FK1C100AR?qs=n%252BNaOaZylkZfYiud3gz9mQ%3D%3D | 0.45 | 2 | 0.9 | 16V
 | Resistencia 120 CRCW0805120RFKEA | https://www.mouser.com/ProductDetail/Vishay/CRCW0805120RFKEA | 0.1 | 4 | 0.4 | 1/4W
 | Resistencia 200 CRCW0805200RKNEAIF | https://www.mouser.com/ProductDetail/Vishay/CRCW0805200RKNEAIF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 | 0.61 | 2 | 1.22 | 1/8W
 | Resistencia 100 CRCW0805100RKNEAIF | https://www.mouser.com/ProductDetail/Vishay/CRCW0805100RKNEAIF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 | 0.61 | 2 | 1.22 | 1/8W
 | Regla de 9 pines hembra M20-7820946 | https://www.mouser.com/ProductDetail/Harwin/M20-7820946?qs=vF78I%252BjhbY9ojjezFz0qqQ%3D%3D | 1.3 | 2
Servomotor | MG996R | Ya tenemos | - | 4 | - | https://www.amazon.com/dp/B0DK1V5ZSM?sp_csd=d2lkZ2V0TmFtZT1zcF9kZXRhaWxfdGhlbWF0aWM
 | Resistencia 330 | https://www.mouser.com/ProductDetail/Vishay/CRCW0805330RFKEA?qs=TrAHXYCGmqx6h6MysZWe0Q%3D%3D | 0.1 | 5 | 0.5 | 1/4W - 1%
 | Capacitor 220uF EEE-FK1C221P | https://www.mouser.com/ProductDetail/Panasonic/EEE-FK1C221P?qs=qE6bgDGEOCsietKYetHWhQ%3D%3D | 0.7 | 5 | 3.5 | 16V
Pantalla LCD | Pantalla LCD 20x4 | Ya tenemos | - | 1 | -
 | PCF8574DWR | https://www.mouser.com/ProductDetail/Texas-Instruments/PCF8574DWR?qs=bkMXpVdiF427kosefzagkg%3D%3D | 1.99 | 2 | 3.98 | https://www.ti.com/lit/ds/symlink/pcf8574.pdf
 | Trimmer 10k 3314G-1-103E | https://www.mouser.com/ProductDetail/Bourns/3314G-1-103E?qs=5DXzRwmrLHHE6mxfh4g4uw%3D%3D | 1.58 | 2 | 3.16 | https://www.mouser.com/datasheet/3/40/1/3314.pdf
 | Transistor SS8050-HF | https://www.mouser.com/ProductDetail/Comchip-Technology/SS8050-HF?qs=T%252BzbugeAwjjubHjgf%252BCy6w%3D%3D | 0.29 | 2 | 0.58 | https://www.mouser.com/datasheet/3/819/1/QW_JTR154_SS8050_HF_RevA.pdf
 | Resistencia 4,7k CRCW08054K70FKEA | https://www.mouser.com/ProductDetail/Vishay/CRCW08054K70FKEA?qs=kkyyugUlSrMIzNiWjd4LGQ%3D%3D | 0.1 | 2 | 0.2 | 1/4W - 1%
 | Resistencia 100 | https://www.mouser.com/ProductDetail/YAGEO/RC0805JR-07100RP?qs=oypCK0zG327LLzJ1KgjADA%3D%3D | 0.1 | 2 | 0.2 | 1/8W - 5%
 | Capacitor 100nF | https://www.mouser.com/ProductDetail/KEMET/C0805C104K5RACTU?qs=Pc30aiB8zWUISNb2Qeyxfw%3D%3D | 0.1 | 2 | 0.2 | 50V
 | Regla de 40 pines macho 61304011121 | https://www.mouser.com/ProductDetail/Wurth-Elektronik/61304011121?qs=PhR8RmCirEZJqAFOTF3fMQ%3D%3D | 1.53 | 2 | 3.06
 | Regla de 16 pines hembra 61301611821 | https://www.mouser.com/ProductDetail/Wurth-Elektronik/61301611821?qs=xZ%2FP%252Ba9zWqYIxo6RU%252B1Wuw%3D%3D | 0.69 | 2 | 1.38
Level Shifter | Resistencia 10k | https://www.mouser.com/ProductDetail/YAGEO/RC0805FR-0710KL?qs=7bY8808IzHq6vrU3BeiiYw%3D%3D | 0.13 | 5 | 0.65 | 1/8W - 1%
 | MOSFET BSS138LT3G | https://www.mouser.com/ProductDetail/onsemi/BSS138LT3G?qs=vNc2DXHODiIFTBAtRV5T3Q%3D%3D | 0.28 | 3 | 0.84 | https://www.mouser.com/datasheet/3/175/1/BSS138.pdf
Camara | Modulo Arducam OV2640 | https://www.amazon.com/Arducam-megap%C3%ADxeles-compatible-Mega2560-Raspberry/dp/B012UXNDOY | 25.99 | 1 | 25.99
 | Capacitor 10uF | https://www.mouser.com/ProductDetail/Murata-Electronics/GCM21BC71C106KE36K?qs=QzBtWTOodeVTOttr1AxchQ%3D%3D | 0.41 | 2 | 0.82 | 16V
 | Capacitor 100nF | https://www.mouser.com/ProductDetail/KEMET/C0805C104K5RACTU?qs=Pc30aiB8zWUISNb2Qeyxfw%3D%3D | 0.1 | 2 | 0.2 | 50V
 | Cable (falta ver cual)
 | Conector macho y hembra (falta ver cual)
Alimentacion | USB-C Alimentacion USB4125-GF-A | https://www.mouser.com/ProductDetail/GCT/USB4125-GF-A?qs=KUoIvG%2F9IlaIQ4zBJ6gLeA%3D%3D | 0.7 | 2 | 1.4
 | Capacitor 100uF EEE-FP1C101AP | https://www.mouser.com/ProductDetail/Panasonic/EEE-FP1C101AP?qs=d1CqaRUMZD%2Fuw16I%252BRuXOw%3D%3D | 0.63 | 2 | 1.26 | 16V
 | Capacitor 100nF | https://www.mouser.com/ProductDetail/KEMET/C0805C104K5RACTU?qs=Pc30aiB8zWUISNb2Qeyxfw%3D%3D | 0.1 | 2 | 0.2 | 50V
 | Resistencia 5.1k CRCW08055K10FKEA | https://www.mouser.com/ProductDetail/Vishay/CRCW08055K10FKEA?qs=8UjxRNpjuUJoSywMOtT5pg%3D%3D | 0.1 | 2 | 0.2
 | Capacitor 1000uF EEE-FN1C102UP | https://www.mouser.com/ProductDetail/Panasonic/EEE-FN1C102UP?qs=OlC7AqGiEDnWpbBcWrASQw%3D%3D | 1.12 | 2 | 2.24 | 16V
 | Switch 7101SYZQE | https://www.mouser.com/ProductDetail/CK/7101SYZQE?qs=V27O%2FkrGudyAxZQ5LSJq7Q%3D%3D | 7.52 | 2 | 15.04 | 5A | 4.7 - 0.76
USB C | USB-C Datos USB4105-GF-A | https://www.mouser.com/ProductDetail/GCT/USB4105-GF-A?qs=KUoIvG%2F9IlY%2FMLlBMpStpA%3D%3D | 0.94 | 2 | 1.88
 | Capacitor 100uF | https://www.mouser.com/ProductDetail/Panasonic/EEE-FP1C101AP?qs=d1CqaRUMZD%2Fuw16I%252BRuXOw%3D%3D | 0.63 | 2 | 1.26 | 16V
 | Capacitor 100nF | https://www.mouser.com/ProductDetail/KEMET/C0805C104K5RACTU?qs=Pc30aiB8zWUISNb2Qeyxfw%3D%3D | 0.1 | 2 | 0.2 | 50V
 | Resistencia 5.1k | https://www.mouser.com/ProductDetail/Vishay/CRCW08055K10FKEA?qs=8UjxRNpjuUJoSywMOtT5pg%3D%3D | 0.1 | 2 | 0.2 | 1/4W - 1%
Proteccion | Diodo Schottky 1N5819HWQ-7-F | https://www.mouser.com/ProductDetail/Diodes-Incorporated/1N5819HWQ-7-F?qs=gZXFycFWdAPDr8BmsK1ygg%3D%3D | 0.43 | 2 | 0.86 | https://4donline.ihs.com/images/VipMasterIC/IC/DIOD/DIOD-S-A0007740344/DIOD-S-A0007740344-1.pdf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
 | MOSFET DMG2305UXQ-7 | https://www.mouser.com/ProductDetail/Diodes-Incorporated/DMG2305UXQ-7?qs=60RJRzIpcl%2FUiAojHt1c9w%3D%3D | 0.36 | 2 | 0.72 | https://www.mouser.com/datasheet/3/175/1/DMG2305UXQ.pdf
 | Resistencia 10k | https://www.mouser.com/ProductDetail/YAGEO/RC0805FR-0710KL?qs=7bY8808IzHq6vrU3BeiiYw%3D%3D | 0.13 | 2 | 0.26
Level Shifter PWM | Level Shifter de 4 canales TXU0104PWR | https://www.mouser.com/ProductDetail/Texas-Instruments/TXU0104PWR?qs=QNEnbhJQKvYcSGbLlthvAQ%3D%3D | 0.99 | 2 | 1.98
 | Capacitor 100nF | https://www.mouser.com/ProductDetail/KEMET/C0805C104K5RACTU?qs=Pc30aiB8zWUISNb2Qeyxfw%3D%3D | 0.1 | 4 | 0.4 | https://www.mouser.com/datasheet/3/72/1/C0805C104K5RACTU.pdf |  |  |  | 50V
 |  |  |  |  | 104

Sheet: Lista_Final
COMPONENTE | MFR NUMBER PART | CANTIDAD | PRECIO |  | TOTAL
ESP32-S3 | ESP32-S3-WROOM-1-N8R8 | 2 | 6.23 |  | 12.46
Regulador LDO de 5V a 3.3V | MIC35302WD-TR | 2 | 1.96 |  | 3.92
LED Naranja (USB_POWER) | HSML-C170-T0000 | 2 | 0.91 |  | 1.82
LED Verde (GENERAL_POWER) | HSMG-C170 | 2 | 0.28 |  | 0.56
LED Amarillo (Pin 38) | HSMY-C170 | 2 | 0.3 |  | 0.6
Switch BOOT y RESET | 430481025816 | 4 | 0.57 |  | 2.28
Resistencia 330 | CRCW0805330RFKEA | 10 | 0.1 |  | 1
Resistencia 100 | CRCW0805100RKNEAIF | 4 | 0.61 |  | 2.44
Resistencia 200 | CRCW0805200RKNEAIF | 2 | 0.61 |  | 1.22
Resistencia 120 | CRCW0805120RFKEA | 4 | 0.1 |  | 0.4
Resistencia 10k | CHP0805AFX-1002ELF | 16 | 0.38 |  | 6.08
Capacitor 100nF | GCM21BR72A104KA37K | 20 | 0.18 |  | 3.6
Capacitor 10uF | GCM21BC71C106KE36K | 6 | 0.41 |  | 2.46
Capacitor 10uF | EEE-FK1C100AR | 2 | 0.45 |  | 0.9
Regla de 9 pines hembra | M20-7820946 | 4 | 1.3 |  | 5.2
USB-C Alimentacion | USB4125-GF-A | 2 | 0.7 |  | 1.4
Capacitor 100uF | EEE-FP1C101AP | 4 | 0.63 |  | 2.52
Resistencia 5.1k | CRCW08055K10FKEA | 8 | 0.1 |  | 0.8
Capacitor 1000uF | EEE-FN1C102UP | 2 | 1.12 |  | 2.24
Switch | 7101SYZQE | 2 | 7.52 |  | 15.04
USB-C Datos | USB4105-GF-A | 2 | 0.94 |  | 1.88
Puente de Diodos | USBLC6-2SC6 | 2 | 0.36 |  | 0.72
Diodo Schottky | 1N5819HWQ-7-F | 2 | 0.43 |  | 0.86
MOSFET | DMG2305UXQ-7 | 2 | 0.36 |  | 0.72
Regla de 16 pines hembra | 61301611821 | 2 | 0.69 |  | 1.38
Regla de 40 pines macho | 61304011121 | 2 | 1.53 |  | 3.06
MOSFET | BSS138LT3G | 4 | 0.28 |  | 1.12
Capacitor 220uF | EEE-FK1C221P | 8 | 0.7 |  | 5.6
Level Shifter de 4 canales | TXU0104PWR | 2 | 0.99 |  | 1.98
I2C Backpack | PCF8574DWR | 2 | 1.99 |  | 3.98
Trimmer 10k | 3314G-1-103E | 2 | 1.58 |  | 3.16
Transistor | SS8050-HF | 2 | 0.29 |  | 0.58
Resistencia 4,7k | CRCW08054K70FKEA | 2 | 0.1 |  | 0.2
Modulo Arducam OV2640 | OV2640 | 1 | 25.99 |  | 25.99
 |  |  |  | TOTAL: | 118.17

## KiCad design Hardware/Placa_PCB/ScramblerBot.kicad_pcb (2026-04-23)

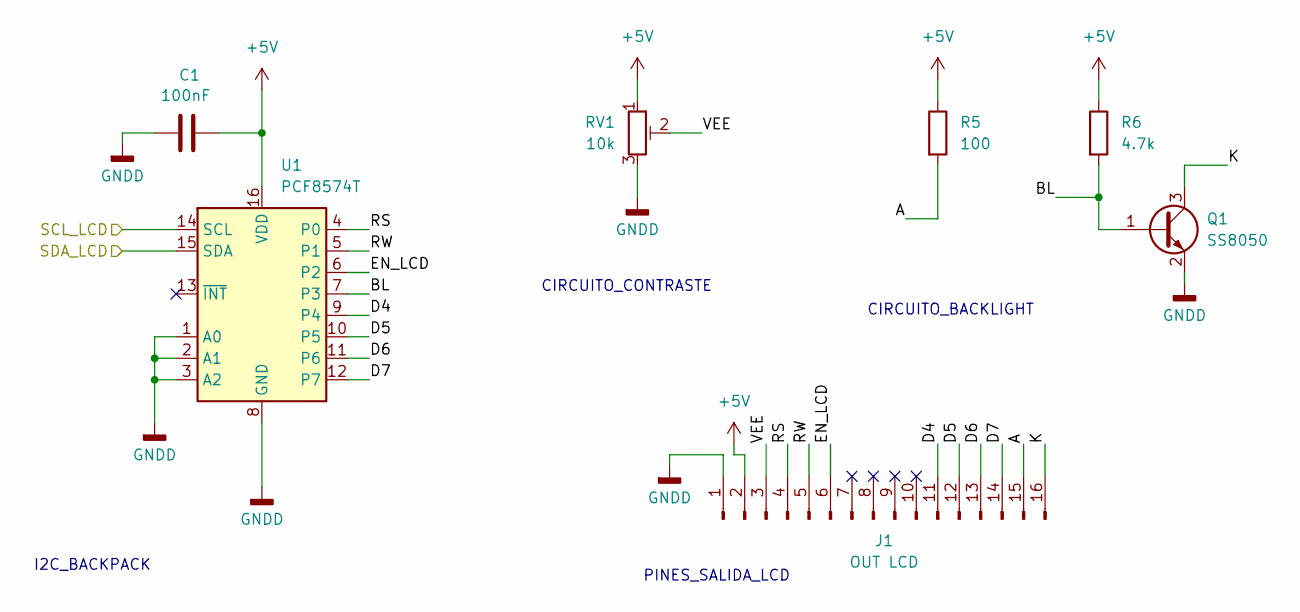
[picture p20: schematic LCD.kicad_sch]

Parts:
C1: 100nF; C_0805_2012Metric_Pad1.18x1.45mm_HandSolder
J1: OUT LCD; PinSocket_1x16_P2.54mm_Vertical
Q1: SS8050; SOT-23
R5: 100; R_0805_2012Metric_Pad1.20x1.40mm_HandSolder
R6: 4.7k; R_0805_2012Metric_Pad1.20x1.40mm_HandSolder
RV1: 10k; Potentiometer_Bourns_3314G_Vertical
U1: PCF8574T; SOIC-16W_7.5x10.3mm_P1.27mm

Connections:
+5V: C1.1, J1.2, R5.1, R6.1, RV1.1, U1.16 (VDD); also elsewhere on the board
/Level Shifter LCD/SCL_LCD: U1.14 (SCL); also elsewhere on the board
/Level Shifter LCD/SDA_LCD: U1.15 (SDA); also elsewhere on the board
/Pantalla_LCD/A: J1.15, R5.2
/Pantalla_LCD/BL: Q1.1 (B), R6.2, U1.7 (P3)
/Pantalla_LCD/D4: J1.11, U1.9 (P4)
/Pantalla_LCD/D5: J1.12, U1.10 (P5)
/Pantalla_LCD/D6: J1.13, U1.11 (P6)
/Pantalla_LCD/D7: J1.14, U1.12 (P7)
/Pantalla_LCD/EN_LCD: J1.6, U1.6 (P2)
/Pantalla_LCD/K: J1.16, Q1.3 (C)
/Pantalla_LCD/RS: J1.4, U1.4 (P0)
/Pantalla_LCD/RW: J1.5, U1.5 (P1)
/Pantalla_LCD/VEE: J1.3, RV1.2
GNDD: C1.2, J1.1, Q1.2 (E), RV1.3, U1.1 (A0), U1.2 (A1), U1.3 (A2), U1.8 (GND); also elsewhere on the board

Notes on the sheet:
CIRCUITO_BACKLIGHT
I2C_BACKPACK
CIRCUITO_CONTRASTE
PINES_SALIDA_LCD

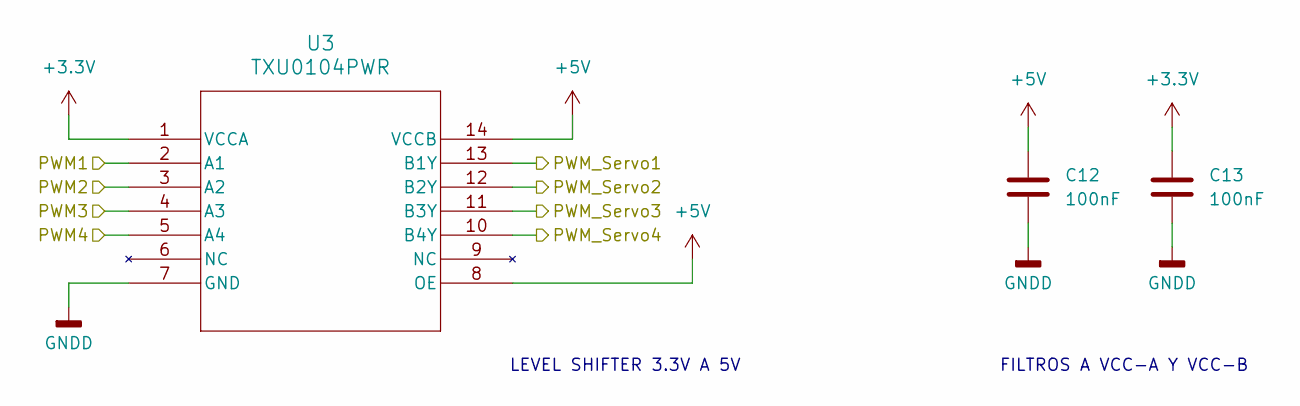
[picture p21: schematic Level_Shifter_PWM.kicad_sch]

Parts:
C12, C13: 100nF; C_0805_2012Metric_Pad1.18x1.45mm_HandSolder
U3: TXU0104PWR; TSSOP-14_4.4x5mm_P0.65mm

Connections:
+3.3V: C13.1, U3.1 (VCCA); also elsewhere on the board
+5V: C12.1, U3.8 (OE), U3.14 (VCCB); also elsewhere on the board
/Level Shifter PWM/PWM1: U3.2 (A1); also elsewhere on the board
/Level Shifter PWM/PWM2: U3.3 (A2); also elsewhere on the board
/Level Shifter PWM/PWM3: U3.4 (A3); also elsewhere on the board
/Level Shifter PWM/PWM4: U3.5 (A4); also elsewhere on the board
/Level Shifter PWM/PWM_Servo1: U3.13 (B1Y); also elsewhere on the board
/Level Shifter PWM/PWM_Servo2: U3.12 (B2Y); also elsewhere on the board
/Level Shifter PWM/PWM_Servo3: U3.11 (B3Y); also elsewhere on the board
/Level Shifter PWM/PWM_Servo4: U3.10 (B4Y); also elsewhere on the board
GNDD: C12.2, C13.2, U3.7 (GND); also elsewhere on the board

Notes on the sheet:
FILTROS A VCC-A Y VCC-B
LEVEL SHIFTER 3.3V A 5V

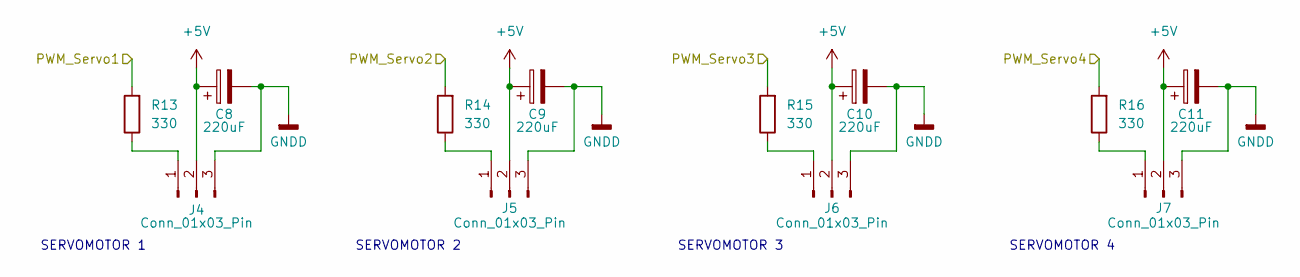
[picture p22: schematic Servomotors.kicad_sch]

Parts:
C8, C9, C10, C11: 220uF; CP_Elec_8x6.2
J4, J5, J6, J7: Conn_01x03_Pin; PinHeader_1x03_P2.54mm_Vertical
R13, R14, R15, R16: 330; R_0805_2012Metric_Pad1.20x1.40mm_HandSolder

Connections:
+5V: C8.1, C9.1, C10.1, C11.1, J4.2, J5.2, J6.2, J7.2; also elsewhere on the board
/Level Shifter PWM/PWM_Servo1: R13.2; also elsewhere on the board
/Level Shifter PWM/PWM_Servo2: R14.2; also elsewhere on the board
/Level Shifter PWM/PWM_Servo3: R15.2; also elsewhere on the board
/Level Shifter PWM/PWM_Servo4: R16.2; also elsewhere on the board
GNDD: C8.2, C9.2, C10.2, C11.2, J4.3, J5.3, J6.3, J7.3; also elsewhere on the board
unnamed: J4.1, R13.1
unnamed: J5.1, R14.1
unnamed: J6.1, R15.1
unnamed: J7.1, R16.1

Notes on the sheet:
SERVOMOTOR 2
SERVOMOTOR 1
SERVOMOTOR 3
SERVOMOTOR 4

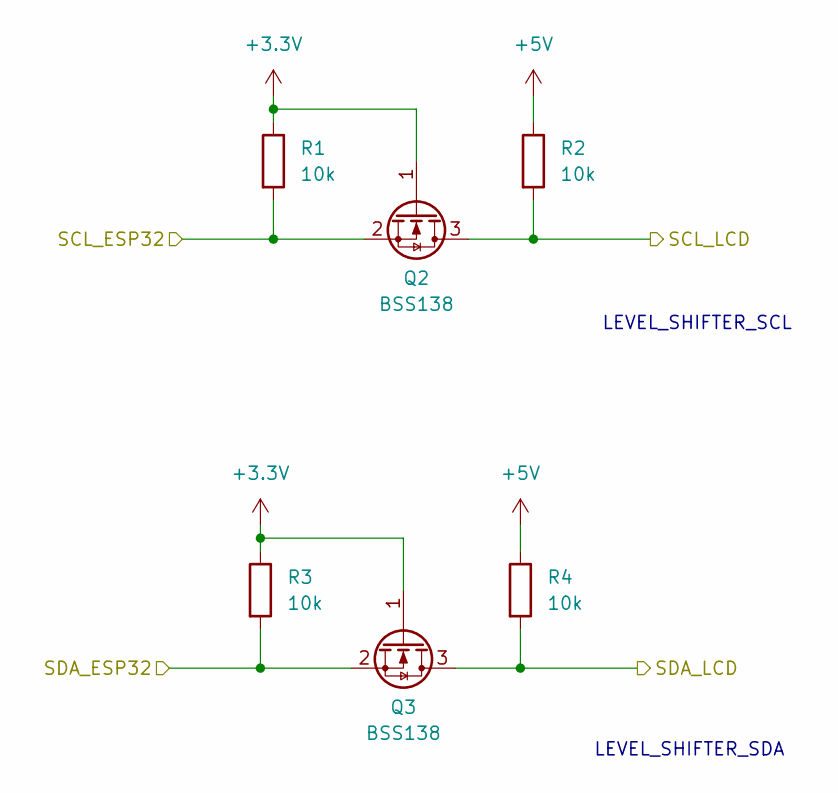
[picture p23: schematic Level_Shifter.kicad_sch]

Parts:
Q2, Q3: BSS138; SOT-23
R1, R2, R3, R4: 10k; R_0805_2012Metric_Pad1.20x1.40mm_HandSolder

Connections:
+3.3V: Q2.1 (G), Q3.1 (G), R1.1, R3.1; also elsewhere on the board
+5V: R2.1, R4.1; also elsewhere on the board
/Level Shifter LCD/SCL_ESP32: Q2.2 (S), R1.2; also elsewhere on the board
/Level Shifter LCD/SCL_LCD: Q2.3 (D), R2.2; also elsewhere on the board
/Level Shifter LCD/SDA_ESP32: Q3.2 (S), R3.2; also elsewhere on the board
/Level Shifter LCD/SDA_LCD: Q3.3 (D), R4.2; also elsewhere on the board

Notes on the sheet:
LEVEL_SHIFTER_SDA
LEVEL_SHIFTER_SCL

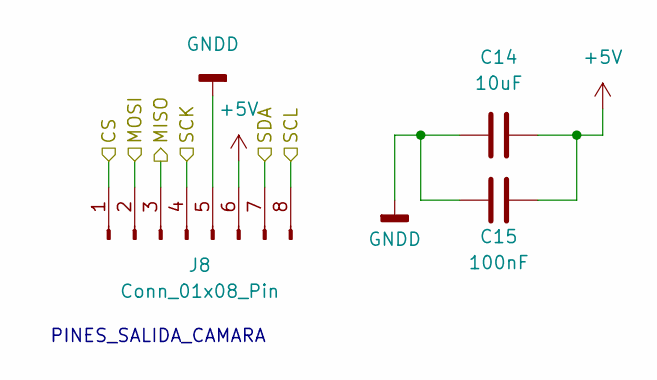
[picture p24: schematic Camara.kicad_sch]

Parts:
C14: 10uF; C_0805_2012Metric_Pad1.18x1.45mm_HandSolder
C15: 100nF; C_0805_2012Metric_Pad1.18x1.45mm_HandSolder
J8: Conn_01x08_Pin; PinHeader_1x08_P2.54mm_Vertical

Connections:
+5V: C14.2, C15.1, J8.6; also elsewhere on the board
/Camara/CS: J8.1; also elsewhere on the board
/Camara/MISO: J8.3; also elsewhere on the board
/Camara/MOSI: J8.2; also elsewhere on the board
/Camara/SCK: J8.4; also elsewhere on the board
/Camara/SCL: J8.8; also elsewhere on the board
/Camara/SDA: J8.7; also elsewhere on the board
GNDD: C14.1, C15.2, J8.5; also elsewhere on the board

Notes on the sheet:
PINES_SALIDA_CAMARA

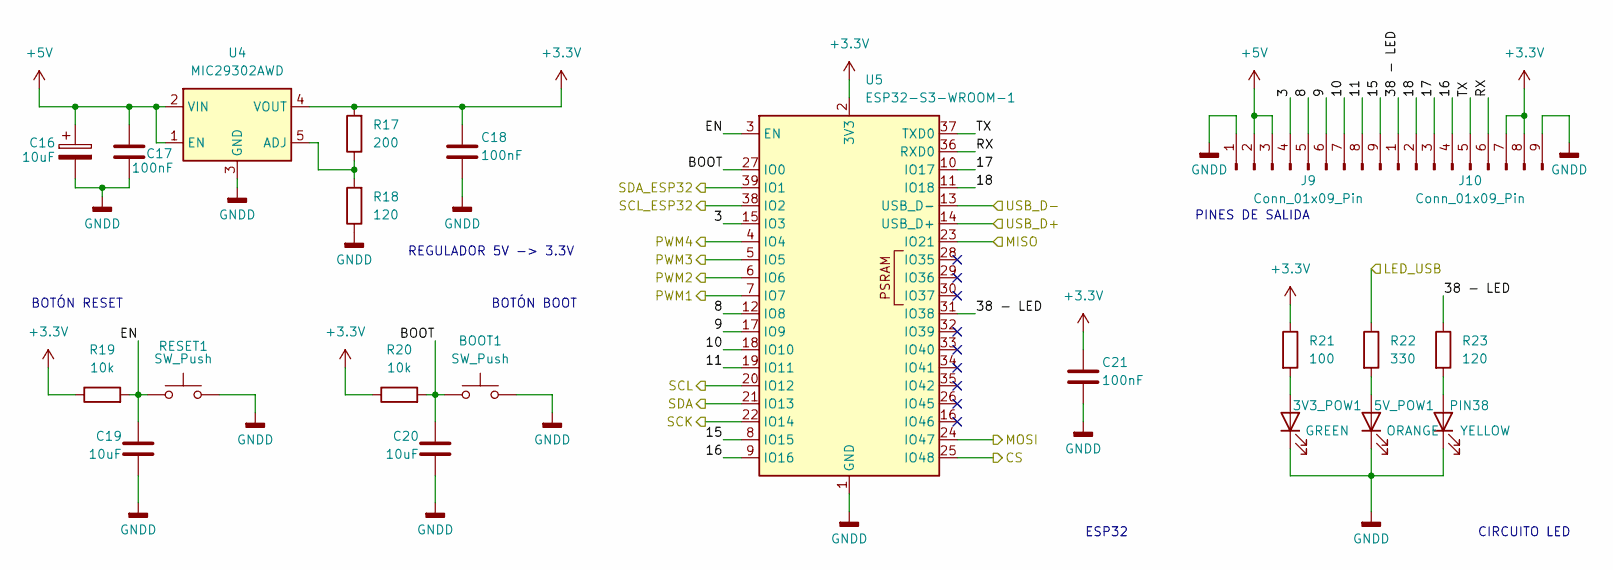
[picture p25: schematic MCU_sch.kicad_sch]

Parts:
3V3_POW1: GREEN; LED_0805_2012Metric_Pad1.15x1.40mm_HandSolder
5V_POW1: ORANGE; LED_0805_2012Metric_Pad1.15x1.40mm_HandSolder
BOOT1: SW_Push; SW_Push_1P1T_NO_E-Switch_TL3301NxxxxxG
C16: 10uF; CP_Elec_4x5.4
C17, C18, C21: 100nF; C_0805_2012Metric_Pad1.18x1.45mm_HandSolder
C19, C20: 10uF; C_0805_2012Metric_Pad1.18x1.45mm_HandSolder
J9, J10: Conn_01x09_Pin; PinSocket_1x09_P2.54mm_Vertical
PIN38: YELLOW; LED_0805_2012Metric_Pad1.15x1.40mm_HandSolder
R17: 200; R_0805_2012Metric_Pad1.20x1.40mm_HandSolder
R18, R23: 120; R_0805_2012Metric_Pad1.20x1.40mm_HandSolder
R19, R20: 10k; R_0805_2012Metric_Pad1.20x1.40mm_HandSolder
R21: 100; R_0805_2012Metric_Pad1.20x1.40mm_HandSolder
R22: 330; R_0805_2012Metric_Pad1.20x1.40mm_HandSolder
RESET1: SW_Push; SW_Push_1P1T_NO_E-Switch_TL3301NxxxxxG
U4: MIC29302AWD; TO-252-5_TabPin3
U5: ESP32-S3-WROOM-1

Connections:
+3.3V: C18.1, C21.1, J10.7, J10.8, R17.2, R19.1, R20.1, R21.1, U4.4 (VOUT), U5.2 (3V3); also elsewhere on the board
+5V: C16.1, C17.1, J9.2, J9.3, U4.1 (EN), U4.2 (VIN); also elsewhere on the board
/Camara/CS: U5.25 (IO48); also elsewhere on the board
/Camara/MISO: U5.23 (IO21); also elsewhere on the board
/Camara/MOSI: U5.24 (IO47); also elsewhere on the board
/Camara/SCK: U5.22 (IO14); also elsewhere on the board
/Camara/SCL: U5.20 (IO12); also elsewhere on the board
/Camara/SDA: U5.21 (IO13); also elsewhere on the board
/Level Shifter LCD/SCL_ESP32: U5.38 (IO2); also elsewhere on the board
/Level Shifter LCD/SDA_ESP32: U5.39 (IO1); also elsewhere on the board
/Level Shifter PWM/PWM1: U5.7 (IO7); also elsewhere on the board
/Level Shifter PWM/PWM2: U5.6 (IO6); also elsewhere on the board
/Level Shifter PWM/PWM3: U5.5 (IO5); also elsewhere on the board
/Level Shifter PWM/PWM4: U5.4 (IO4); also elsewhere on the board
/MCU/3: J9.4, U5.15 (IO3)
/MCU/8: J9.5, U5.12 (IO8)
/MCU/9: J9.6, U5.17 (IO9)
/MCU/10: J9.7, U5.18 (IO10)
/MCU/11: J9.8, U5.19 (IO11)
/MCU/15: J9.9, U5.8 (IO15)
/MCU/16: J10.4, U5.9 (IO16)
/MCU/17: J10.3, U5.10 (IO17)
/MCU/18: J10.2, U5.11 (IO18)
/MCU/38 - LED: J10.1, R23.1, U5.31 (IO38)
/MCU/BOOT: BOOT1.1, C20.1, R20.2, U5.27 (IO0)
/MCU/EN: C19.1, R19.2, RESET1.1, U5.3 (EN)
/MCU/LED_USB: R22.1; also elsewhere on the board
/MCU/RX: J10.6, U5.36 (RXD0)
/MCU/TX: J10.5, U5.37 (TXD0)
/MCU/USB_D+: U5.14 (USB_D+); also elsewhere on the board
/MCU/USB_D-: U5.13 (USB_D-); also elsewhere on the board
GNDD: 3V3_POW1.1 (K), 5V_POW1.1 (K), BOOT1.2, C16.2, C17.2, C18.2, C19.2, C20.2, C21.2, J9.1, J10.9, PIN38.1 (K), R18.1, RESET1.2, U4.3 (GND), U5.1 (GND), U5.40 (GND), U5.41 (GND); also elsewhere on the board
unnamed: 3V3_POW1.2 (A), R21.2
unnamed: 5V_POW1.2 (A), R22.2
unnamed: PIN38.2 (A), R23.2
unnamed: R17.1, R18.2, U4.5 (ADJ)

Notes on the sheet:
REGULADOR 5V -> 3.3V
CIRCUITO LED
BOTÓN BOOT
PINES DE SALIDA
BOTÓN RESET
ESP32

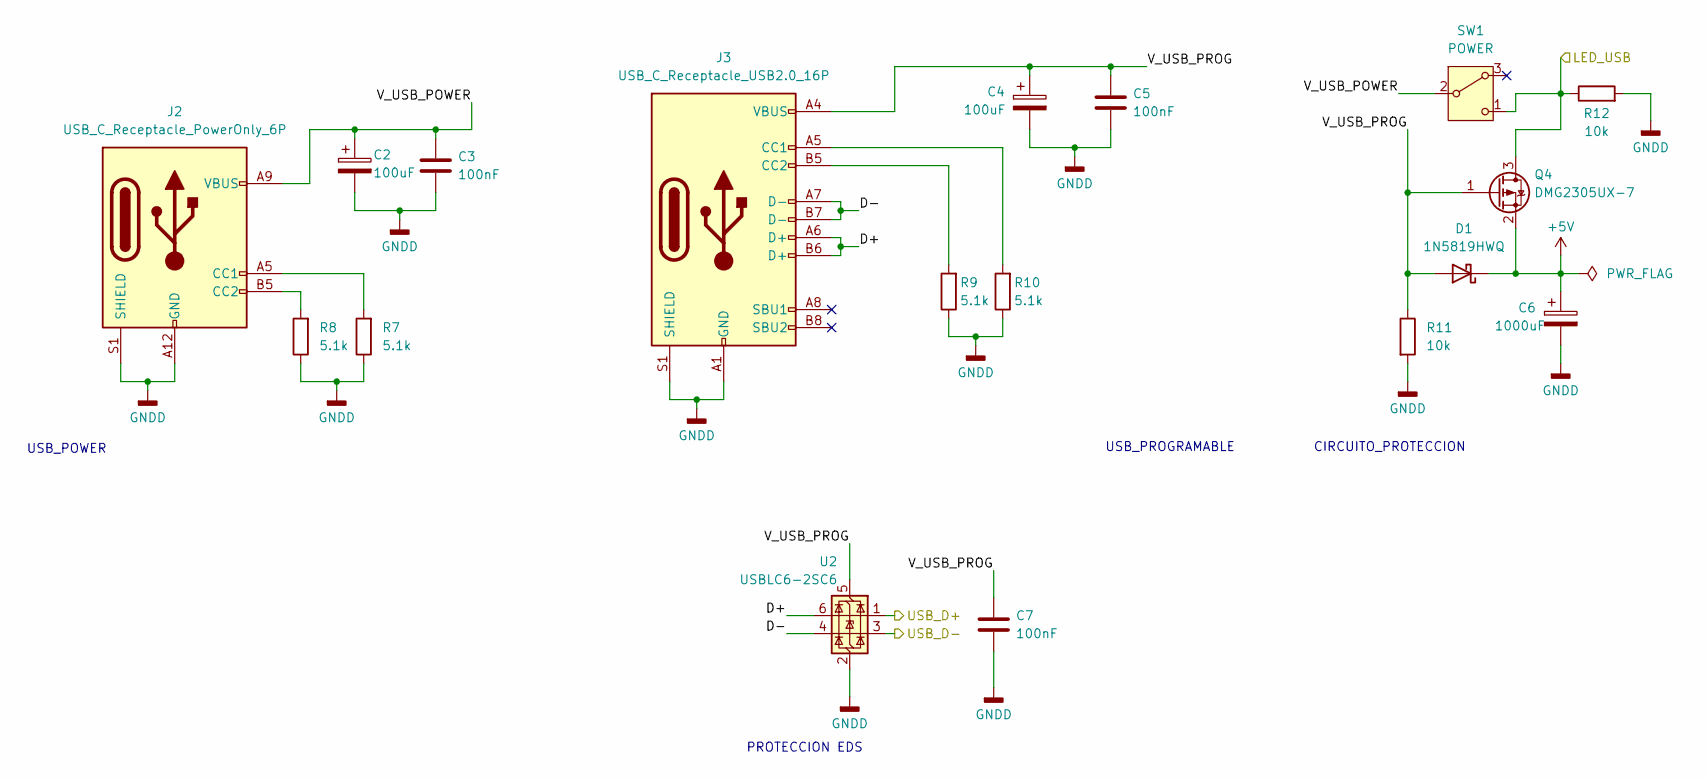
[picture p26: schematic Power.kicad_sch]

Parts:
C2, C4: 100uF; CP_Elec_6.3x5.8
C3, C5, C7: 100nF; C_0805_2012Metric_Pad1.18x1.45mm_HandSolder
C6: 1000uF; CP_Elec_10x10.5
D1: 1N5819HWQ; D_SOD-123
J2: USB_C_Receptacle_PowerOnly_6P; USB_C_Receptacle_GCT_USB4125-xx-x-0190_6P_TopMnt_Horizontal
J3: USB_C_Receptacle_USB2.0_16P; USB_C_Receptacle_HRO_TYPE-C-31-M-12
Q4: DMG2305UX-7; SOT-23
R7, R8, R9, R10: 5.1k; R_0805_2012Metric_Pad1.20x1.40mm_HandSolder
R11, R12: 10k; R_0805_2012Metric_Pad1.20x1.40mm_HandSolder
SW1: POWER; SW_100SP1T_12P7X6P86_EWI
U2: USBLC6-2SC6; SOT-23-6

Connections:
+5V: C6.1, D1.1 (K), Q4.2 (S); also elsewhere on the board
/MCU/LED_USB: Q4.3 (D), R12.1, SW1.1 (C); also elsewhere on the board
/MCU/USB_D+: U2.1 (I/O1); also elsewhere on the board
/MCU/USB_D-: U2.3 (I/O2); also elsewhere on the board
/Power__USB_C/D+: J3.A6 (D+), J3.B6 (D+), U2.6 (I/O1)
/Power__USB_C/D-: J3.A7 (D-), J3.B7 (D-), U2.4 (I/O2)
/Power__USB_C/V_USB_POWER: C2.1, C3.1, J2.A9 (VBUS), J2.B9 (VBUS), SW1.2 (B)
/Power__USB_C/V_USB_PROG: C4.1, C5.1, C7.1, D1.2 (A), J3.A4 (VBUS), J3.A9 (VBUS), J3.B4 (VBUS), J3.B9 (VBUS), Q4.1 (G), R11.1, U2.5 (VBUS)
GNDD: C2.2, C3.2, C4.2, C5.2, C6.2, C7.2, J2.A12 (GND), J2.B12 (GND), J2.S1 (SHIELD), J3.A1 (GND), J3.A12 (GND), J3.B1 (GND), J3.B12 (GND), J3.S1 (SHIELD), R7.1, R8.1, R9.1, R10.1, R11.2, R12.2, U2.2 (GND); also elsewhere on the board
unnamed: J2.A5 (CC1), R7.2
unnamed: J2.B5 (CC2), R8.2
unnamed: J3.A5 (CC1), R10.2
unnamed: J3.B5 (CC2), R9.2

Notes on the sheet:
CIRCUITO_PROTECCION
PROTECCION EDS
USB_POWER
USB_PROGRAMABLE

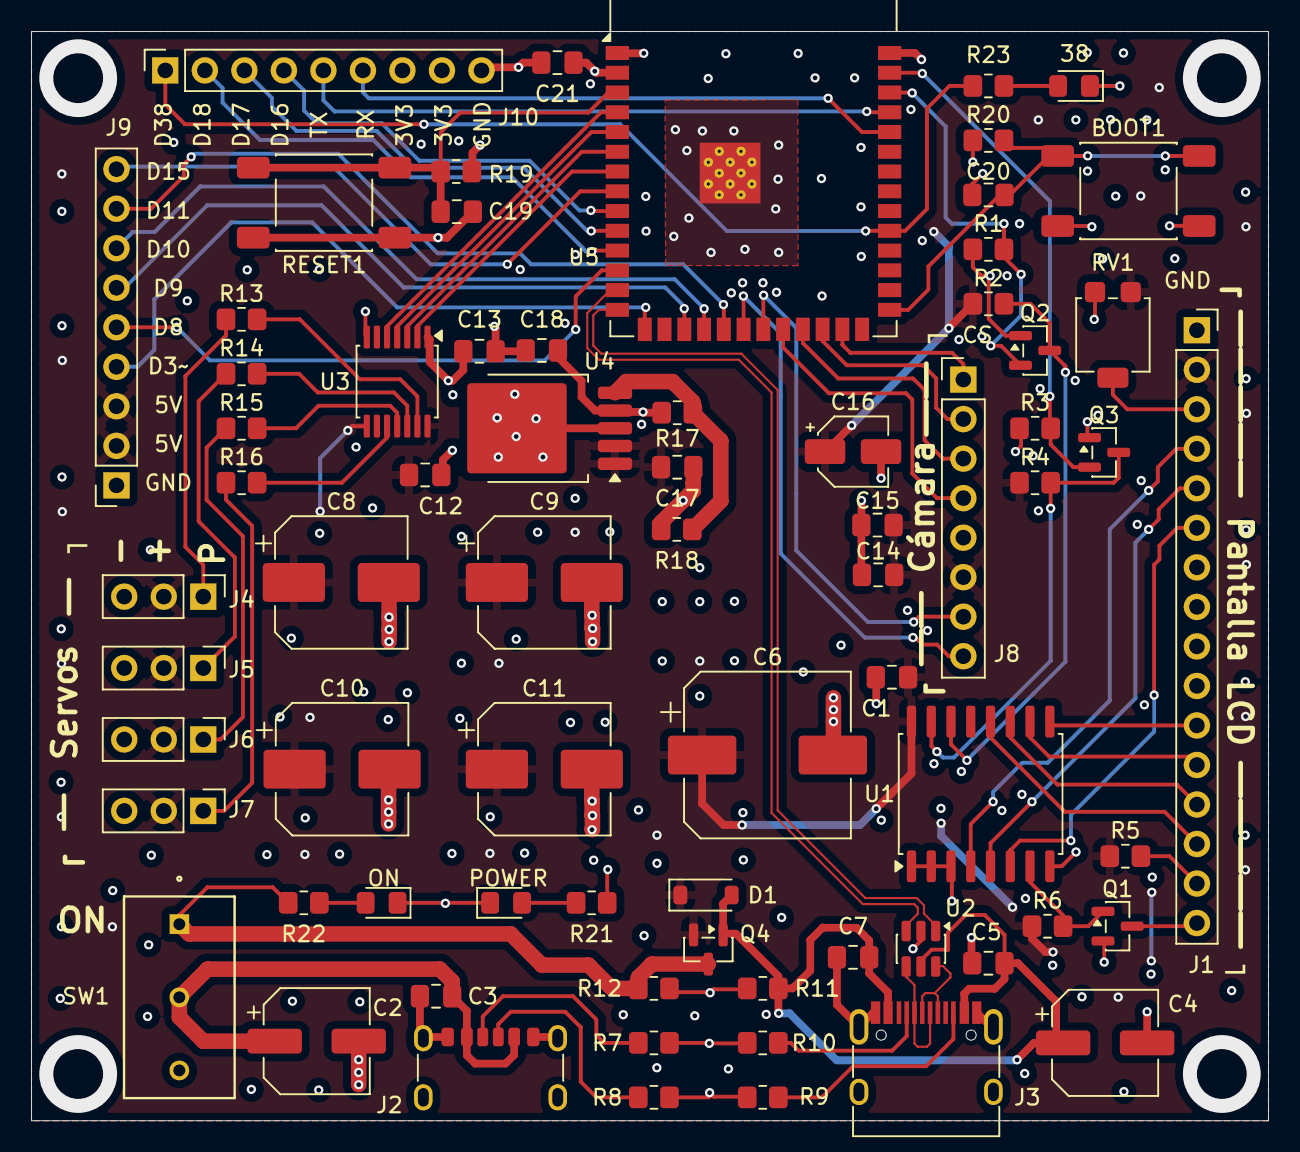
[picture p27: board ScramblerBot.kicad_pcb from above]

Board: 4 copper layers, 79.5 x 70.0 mm, 71 parts (0 on the bottom side), 65 nets.

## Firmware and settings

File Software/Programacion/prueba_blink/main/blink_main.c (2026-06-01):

// Incluimos las librerias principales
# include <stdio.h>
# include "freertos/FreeRTOS.h"
# include "freertos/task.h"
# include "driver/gpio.h"

# define BLINK_GPIO 38 // LED de la placa -> GPIO 38

static uint8_t estado = 0; // Estado actual del led

void app_main ( void )
{
    // Resetear y configurar el GPIO 38 como salida
    gpio_reset_pin ( BLINK_GPIO ) ;
    gpio_set_direction ( BLINK_GPIO , GPIO_MODE_OUTPUT ) ;

    while (1) {
        gpio_set_level ( BLINK_GPIO , estado ) ;
        estado = ! estado ; // Cambia entre 0 y 1
        // Delay de 500 ms usando los ticks del RTOS
        vTaskDelay (500 / portTICK_PERIOD_MS );
    }
}

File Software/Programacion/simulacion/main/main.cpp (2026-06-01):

#include <stdio.h>
#include "freertos/FreeRTOS.h"
#include "freertos/task.h"
#include "lcd.h"
#include "servo.h"

// Macros de tiempos 
#define TIEMPO_SALUDO_MS      5000   // 5 segundos
#define TIEMPO_RESOLVIENDO_MS 10000  // 10 segundos
#define TIEMPO_PAUSA_MS       2000   // 2 segundos (¡Faltaba este!)

// El 'extern "C"' para que reconozca la funcion principal
extern "C" void app_main(void) 
{
    // Inicializacion del hardware
    lcd_init();
    servo_init();

    // Mensaje inicial
    lcd_clear();
    lcd_set_cursor(0, 0);
    lcd_print("Hola soy ");
    lcd_set_cursor(0, 1);
    lcd_print("ScramblerBot!!");
    vTaskDelay(TIEMPO_SALUDO_MS / portTICK_PERIOD_MS);

    // Imprimimos la base del mensaje en pantalla 
    lcd_clear();
    lcd_set_cursor(0, 0);
    lcd_print("Resolviendo...");
    lcd_set_cursor(0, 1);
    lcd_print("Movimientos: ");

    // Tomamos la marca de tiempo actual en milisegundos
    TickType_t tiempo_inicio = xTaskGetTickCount() * portTICK_PERIOD_MS;

    // Mientras no hayan pasado 10 segundos, repetimos la secuencia
    while (((xTaskGetTickCount() * portTICK_PERIOD_MS) - tiempo_inicio) < TIEMPO_RESOLVIENDO_MS) {
        
        // Convertimos el numero entero a texto para que la LCD lo entienda
        char buffer_texto[16]; // Creamos un espacio temporal en memoria
        snprintf(buffer_texto, sizeof(buffer_texto), "%d", contador_movimientos);
        
        // Imprimimos solo el numero actualizado en la posicion correcta
        lcd_set_cursor(13, 1);
        lcd_print(buffer_texto);
        
        mover_servos_secuencia();
    }

    // Pausa
    vTaskDelay(TIEMPO_PAUSA_MS / portTICK_PERIOD_MS);

    // Mensaje final
    lcd_clear();
    lcd_set_cursor(0, 0);
    lcd_print("Cubo Resuelto!!");
}

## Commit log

2026-02-25 Create Schematic
2026-02-25 Update and rename Lista_Actuadores_Periféricos to Lista_Actuadores_Periféricos.xls
    [Lista_Actuadores_Periféricos.xls]
2026-03-09 Agregando carpeta Placa_PCB dentro del Hardware y los archivos Kicad
    [Camara.kicad_sch, LCD.kicad_sch, Level_Shifter.kicad_sch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]
2026-03-09 Agregando excel de Lista de Componentes dentro de la carpeta Hardware
    [Lista_Componentes - Componentes por Bloque.csv]
2026-03-10 Cambiando descripcion de la camara
2026-03-11 Agregando Level Shifter al PWM del Servo
    [Level_Shifter_PWM.kicad_sch, MCU_sch.kicad_sch, ScramblerBot.kicad_sch]
2026-03-11 Agregando carpeta Assets para los simbolos que no existen
2026-03-13 Agregando MCU al esquematico
    [Camara.kicad_sch, Level_Shifter_PWM.kicad_sch, MCU_sch.kicad_sch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]
2026-03-15 Esquematico Final
    [Camara.kicad_sch, Level_Shifter_PWM.kicad_sch, MCU_sch.kicad_sch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]
2026-03-16 Agregando huella del capacitor de 10uF y comenzando con el PCB (USB + Alimentacion)
    [MCU_sch.kicad_sch, ScramblerBot.kicad_pcb]
2026-03-18 Acomodando los componentes en el PCB y cambiendo las conexiones con el ESP32
    [MCU_sch.kicad_sch, ScramblerBot.kicad_pcb]
2026-03-19 Terminando el enrutado de los +5V y comenzando las pistas de 3.3V
    [MCU_sch.kicad_sch, ScramblerBot.kicad_pcb]
2026-03-21 Actualizacion de PCB con rellenos ordenados, solo falta colocar las vias
    [Camara.kicad_sch, MCU_sch.kicad_sch, ScramblerBot.kicad_pcb]
2026-03-21 PCB Final 1
    [ScramblerBot.kicad_pcb]
2026-03-21 Acomodando capacitor electrolitico de entrada
    [ScramblerBot.kicad_pcb]
2026-03-28 Cambiando algunos errores de DMF y creando Gerbers
    [ScramblerBot-B_Cu.gbl, ScramblerBot-B_Mask.gbs, ScramblerBot-B_Silkscreen.gbo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]
2026-03-30 Agregando Lista_Componentes.xls e Informe.pdf dentro de la carpeta Informe
    [Lista_Componentes - Componentes por Bloque.csv, Lista_Componentes.xlsx]
2026-04-23 Gerber Final
    [ScramblerBot-B_Cu.gbr, ScramblerBot-B_Mask.gbr, ScramblerBot-B_Paste.gbr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]
2026-05-28 Creamos el primer codigo de prueba 'hello_world' dentro de Software
2026-08-24 Creacion de los scripts de python para el reconocimiento de colores
2026-09-21 Insertando el informe del Primer Parcial en la carpeta Informe/P4
2026-09-21 Archivos STL de las piezas del robot
2026-10-18 Actualizacion GUI y codigos de python
2026-11-06 Codigo ScramblerBotv2 en carpeta ESP32
